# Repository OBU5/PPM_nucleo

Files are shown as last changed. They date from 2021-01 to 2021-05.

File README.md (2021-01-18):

# Proton precession magnetometer

Official repository for Proton precession magnetometer
In this repository are HW and SW files for the diploma thesis that is about designing, constrocting of proton precession magnetometer and analysis of its signal.
The aim is to construct PPM device that will be used for the earth’s magnetic field measurement

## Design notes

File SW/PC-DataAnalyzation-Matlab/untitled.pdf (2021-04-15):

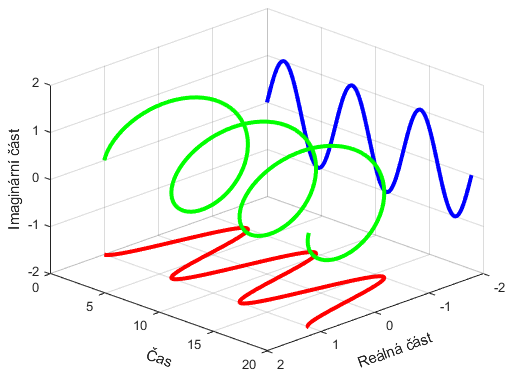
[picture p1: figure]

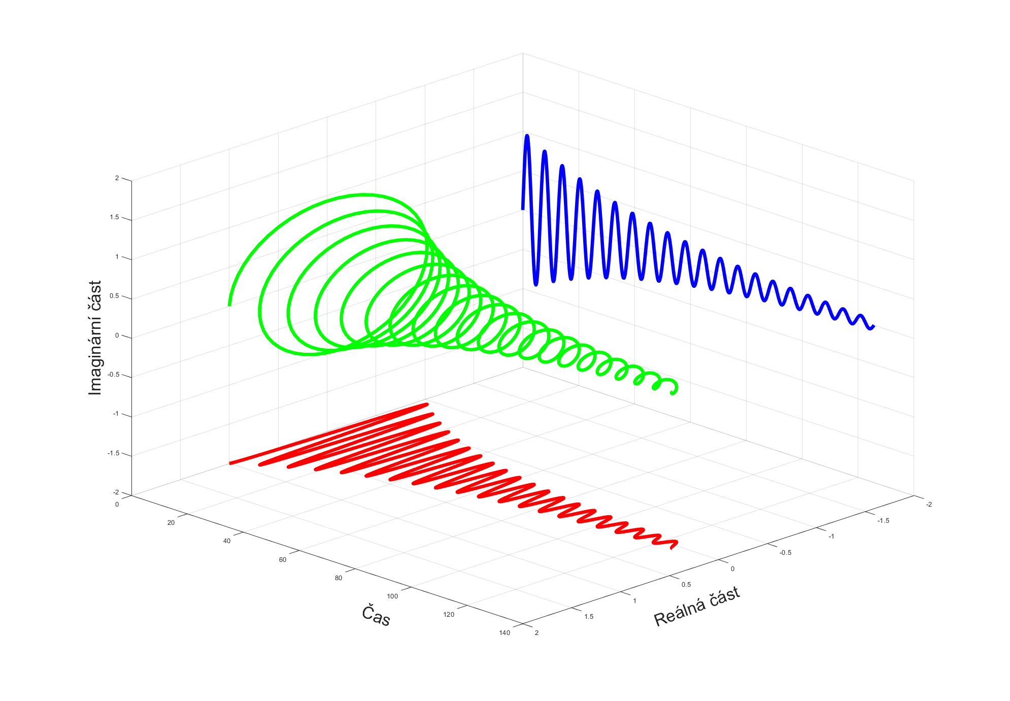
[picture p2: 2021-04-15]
SW/PC-DataAnalyzation-Matlab/complexGraph2.png

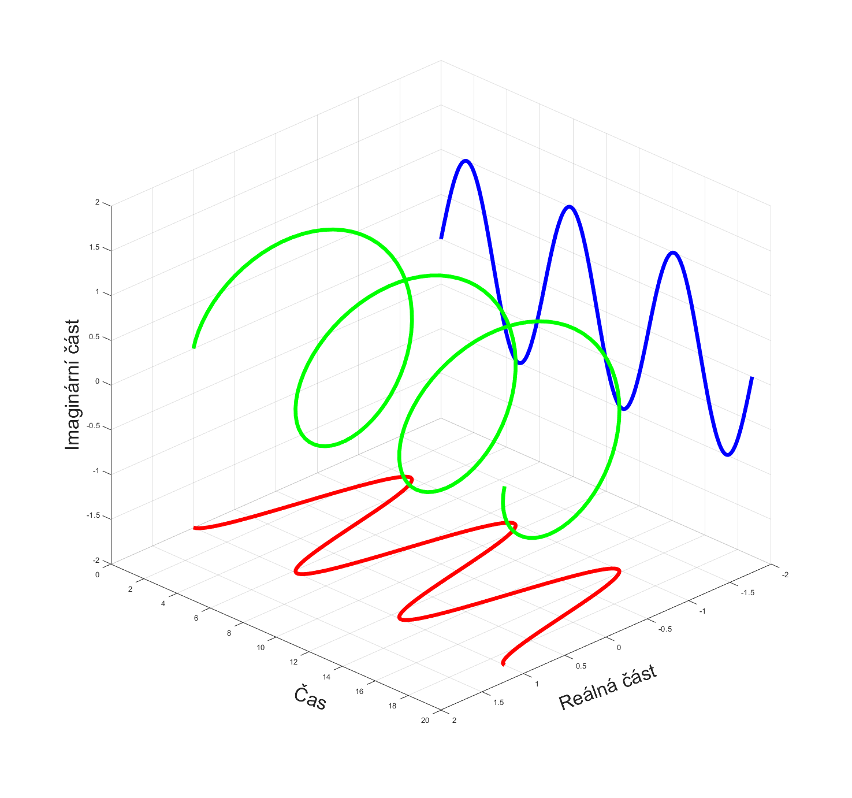
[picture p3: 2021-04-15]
SW/PC-DataAnalyzation-Matlab/complexGraph.png

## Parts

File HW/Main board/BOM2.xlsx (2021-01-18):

Ref | Value | Part | Footprint | Description | Code | count | which shopping cart | Column3 | Column6 | Column7 | Column8 | Column9 | Column10 | Column11 | Column12 | Column13 | Column14 | Column15 | Column16 | Column17 | Column18 | Column19 | Column20 | Column21 | Column22 | Column23 | Column24 | Column25 | Column26 | Column27 | Column28 | Column29 | Column30 | Column31 | Column32 | Column33 | Column34 | Column35 | Column36 | Column37 | Column38 | Column39 | Column40 | Column41 | Column42 | Column43 | Column44 | Column45 | Column46 | Column47 | Column48 | Column49 | Column50 | Column51 | Column52 | Column53 | Column54 | Column55 | Column56
Source: | C:\Users\obu\OneDrive\Documents\CVUT\ING\Diplomka\HW\Kicad\PPM\Ver. 1.6\PPM.sch
Date: | 11/26/2020 9:22:03 PM
Tool: | Eeschema (5.1.4)-1
Component Count: | 388
Ref | Value | Part | Footprint | Description | Vendor | kolik kusů | Jaký košík
BTN1 | User btn | Switch:SW_Push | Button_Switch_THT:SW_PUSH_6mm | Push button switch, generic, two pins | SKHHDTA010 | 3 | MOUSER
BTN2 | User btn | Switch:SW_Push | Button_Switch_THT:SW_PUSH_6mm | Push button switch, generic, two pins | SKHHDTA010 | 3 | MOUSER
BTN3 | RESET | Switch:SW_Push | Button_Switch_THT:SW_PUSH_6mm | Push button switch, generic, two pins | SKHHDTA010 | 3 | MOUSER
C1 | 100n | Device:C | Mylib_Footprints:C0805 | Unpolarized capacitor |  |  | Snad najdu ve škole
C2 | 10u | Device:C | Mylib_Footprints:C1206 | Unpolarized capacitor |  |  | Snad najdu ve škole
C3 | 100n | Device:C | Mylib_Footprints:C0805 | Unpolarized capacitor |  |  | Snad najdu ve škole
C4 | 10u | Device:C | Mylib_Footprints:C1206 | Unpolarized capacitor |  |  | Snad najdu ve škole
C5 | 100n | Device:C | Mylib_Footprints:C0805 | Unpolarized capacitor |  |  | Snad najdu ve škole
C6 | 10u | Device:C | Mylib_Footprints:C1206 | Unpolarized capacitor |  |  | Snad najdu ve škole
C7 | 100n | Device:C | Mylib_Footprints:C0805 | Unpolarized capacitor |  |  | Snad najdu ve škole
C8 | 10u | Device:C | Mylib_Footprints:C1206 | Unpolarized capacitor |  |  | Snad najdu ve škole
C9 | 100n | Device:C | Mylib_Footprints:C0805 | Unpolarized capacitor |  |  | Snad najdu ve škole
C10 | 10u | Device:C | Mylib_Footprints:C1206 | Unpolarized capacitor |  |  | Snad najdu ve škole
C11 | 10u | Device:C | Mylib_Footprints:C1206 | Unpolarized capacitor |  |  | Snad najdu ve škole
C12 | 10u | Device:C | Mylib_Footprints:C1206 | Unpolarized capacitor |  |  | Snad najdu ve škole
C13 | 100u tantal | Device:CP | Capacitor_Tantalum_SMD:CP_EIA-6032-28_Kemet-C | Polarized capacitor | T495C107K010ATE250 (https://cz.mouser.com/ProductDetail/KEMET/T495C107K010ATE250?qs=Dbnw6jgPYP7KOtkzNJv%252BLA%3D%3D) | 2 | MOUSER
C14 | 100u | Device:CP | Capacitor_THT:CP_Radial_D8.0mm_P3.50mm | Polarized capacitor | UPW1H101MPD | 2 | MOUSER
C15 | 1m | Device:CP | Capacitor_THT:CP_Radial_D12.5mm_P5.00mm | Polarized capacitor | EEU-FC1H102L | 1 | MOUSER
C16 | 100u | Device:CP | Capacitor_THT:CP_Radial_D8.0mm_P3.50mm | Polarized capacitor | UPW1H101MPD | 2 | MOUSER
C17 | 10u | Device:C | Mylib_Footprints:C1206 | Unpolarized capacitor |  |  | Snad najdu ve škole
C18 | 10n | Device:C | Mylib_Footprints:C0805 | Unpolarized capacitor |  |  | Snad najdu ve škole
C19 | 10u | Device:C | Mylib_Footprints:C1206 | Unpolarized capacitor |  |  | Snad najdu ve škole
C20 | 1u | Device:C | Mylib_Footprints:C0805 | Unpolarized capacitor |  |  | Snad najdu ve škole
C21 | 100n | Device:C | Capacitor_THT:C_Rect_L7.2mm_W2.5mm_P5.00mm_FKS2_FKP2_MKS2_MKP2 | Unpolarized capacitor | MMK5104J63J01L16.5TA18 | 8 | MOUSER
C22 | 100n | Device:C | Capacitor_THT:C_Rect_L7.2mm_W2.5mm_P5.00mm_FKS2_FKP2_MKS2_MKP2 | Unpolarized capacitor | MMK5104J63J01L16.5TA18 | 8 | MOUSER
C23 | 100n | Device:C | Capacitor_THT:C_Rect_L7.2mm_W2.5mm_P5.00mm_FKS2_FKP2_MKS2_MKP2 | Unpolarized capacitor | MMK5104J63J01L16.5TA18 | 8 | MOUSER
C24 | 100n | Device:C | Capacitor_THT:C_Rect_L7.2mm_W2.5mm_P5.00mm_FKS2_FKP2_MKS2_MKP2 | Unpolarized capacitor | MMK5104J63J01L16.5TA18 | 8 | MOUSER
C25 | 10u | Device:C | Mylib_Footprints:C1206 | Unpolarized capacitor |  |  | Snad najdu ve škole
C26 | 100n | Device:C | Mylib_Footprints:C0805 | Unpolarized capacitor |  |  | Snad najdu ve škole
C27 | 100n | Device:C | Capacitor_THT:C_Rect_L7.2mm_W2.5mm_P5.00mm_FKS2_FKP2_MKS2_MKP2 | Unpolarized capacitor | MMK5104J63J01L16.5TA18 | 8 | MOUSER
C28 | 100n | Device:C | Capacitor_THT:C_Rect_L7.2mm_W2.5mm_P5.00mm_FKS2_FKP2_MKS2_MKP2 | Unpolarized capacitor | MMK5104J63J01L16.5TA18 | 8 | MOUSER
C29 | 100n | Device:C | Capacitor_THT:C_Rect_L7.2mm_W2.5mm_P5.00mm_FKS2_FKP2_MKS2_MKP2 | Unpolarized capacitor | MMK5104J63J01L16.5TA18 | 8 | MOUSER
C30 | 100n | Device:C | Capacitor_THT:C_Rect_L7.2mm_W2.5mm_P5.00mm_FKS2_FKP2_MKS2_MKP2 | Unpolarized capacitor | MMK5104J63J01L16.5TA18 | 8 | MOUSER
C31 | 100n | Device:C | Mylib_Footprints:C0805 | Unpolarized capacitor |  |  | Snad najdu ve škole
C32 | 1u | Device:C | Mylib_Footprints:C0805 | Unpolarized capacitor |  |  | Snad najdu ve škole
C33 | 100n | Device:C | Mylib_Footprints:C0805 | Unpolarized capacitor |  |  | Snad najdu ve škole
C34 | 100n | Device:C | Mylib_Footprints:C0805 | Unpolarized capacitor |  |  | Snad najdu ve škole
C35 | 100n | Device:C | Mylib_Footprints:C0805 | Unpolarized capacitor |  |  | Snad najdu ve škole
C36 | 10u | Device:C | Mylib_Footprints:C1206 | Unpolarized capacitor |  |  | Snad najdu ve škole
C37 | 100u tantal | Device:CP | Capacitor_Tantalum_SMD:CP_EIA-7343-20_Kemet-V | Polarized capacitor | T495X107M025ATE150 | 1 | MOUSER
C38 | 100n | Device:C | Mylib_Footprints:C0805 | Unpolarized capacitor |  |  | Snad najdu ve škole
C39 | 10u | Device:C | Mylib_Footprints:C1206 | Unpolarized capacitor |  |  | Snad najdu ve škole
C40 | 100n | Device:C | Mylib_Footprints:C0805 | Unpolarized capacitor |  |  | Snad najdu ve škole
C41 | 100n | Device:C | Mylib_Footprints:C0805 | Unpolarized capacitor |  |  | Snad najdu ve škole
C42 | 10u | Device:C | Mylib_Footprints:C1206 | Unpolarized capacitor |  |  | Snad najdu ve škole
C43 | 100n | Device:C | Mylib_Footprints:C0805 | Unpolarized capacitor |  |  | Snad najdu ve škole
C44 | 4.3p | Device:C | Mylib_Footprints:C0805 | Unpolarized capacitor | 08055A4R3CAT2A | 2 | MOUSER
C45 | 100n | Device:C | Mylib_Footprints:C0805 | Unpolarized capacitor |  |  | Snad najdu ve škole
C46 | 100u tantal | Device:CP | Capacitor_Tantalum_SMD:CP_EIA-6032-28_Kemet-C | Polarized capacitor | T495C107K010ATE250 (https://cz.mouser.com/ProductDetail/KEMET/T495C107K010ATE250?qs=Dbnw6jgPYP7KOtkzNJv%252BLA%3D%3D) | 2 | MOUSER
C47 | 4.3p | Device:C | Mylib_Footprints:C0805 | Unpolarized capacitor | 08055A4R3CAT2A | 2 | MOUSER
C48 | 100p | Device:C | Mylib_Footprints:C0805 | Unpolarized capacitor | C0805C101G5HACTU | 2 | MOUSER
C49 | 100p | Device:C | Mylib_Footprints:C0805 | Unpolarized capacitor | C0805C101G5HACTU | 2 | MOUSER
C50 | 100n | Device:C | Mylib_Footprints:C0805 | Unpolarized capacitor |  |  | Snad najdu ve škole
C51 | 10u | Device:C | Mylib_Footprints:C1206 | Unpolarized capacitor |  |  | Snad najdu ve škole
C52 | 470u | Device:CP | Capacitor_THT:CP_Radial_D10.0mm_P5.00mm | Polarized capacitor | ESH477M050AH4AA | 1 | MOUSER
C53 | 2200p | Device:C | Mylib_Footprints:C0805 | Unpolarized capacitor | 08055C222M4T4A | 1 | MOUSER
C54 | 10u | Device:C | Mylib_Footprints:C1206 | Unpolarized capacitor |  |  | Snad najdu ve škole
C55 | 100n | Device:C | Mylib_Footprints:C0805 | Unpolarized capacitor |  |  | Snad najdu ve škole
C56 | 1u | Device:C | Mylib_Footprints:C0805 | Unpolarized capacitor |  |  | Snad najdu ve škole
C57 | 100n | Device:C | Mylib_Footprints:C0805 | Unpolarized capacitor |  |  | Snad najdu ve škole
C58 | 10u | Device:C | Mylib_Footprints:C1206 | Unpolarized capacitor |  |  | Snad najdu ve škole
C59 | 10u | Device:C | Mylib_Footprints:C1206 | Unpolarized capacitor |  |  | Snad najdu ve škole
C60 | 100n | Device:C | Mylib_Footprints:C0805 | Unpolarized capacitor |  |  | Snad najdu ve škole
C61 | 100n | Device:C | Mylib_Footprints:C0805 | Unpolarized capacitor |  |  | Snad najdu ve škole
C62 | 2.2u | Device:C | Mylib_Footprints:C1206 | Unpolarized capacitor | UMK212BB7225KG-T | 2 | MOUSER
C63 | 2.2u | Device:C | Mylib_Footprints:C1206 | Unpolarized capacitor | UMK212BB7225KG-T | 2 | MOUSER
C64 | 470n | Device:C | Mylib_Footprints:C0805 | Unpolarized capacitor | C0805C474M5REC7210 | 1 | MOUSER
C65 | 100n | Device:C | Mylib_Footprints:C0805 | Unpolarized capacitor |  |  | Snad najdu ve škole
C66 | 47u | Device:CP | Capacitor_Tantalum_SMD:CP_EIA-6032-28_Kemet-C | Polarized capacitor | T495C476K010ATE300 | 3 | MOUSER
C67 | 10u | Device:C | Mylib_Footprints:C1206 | Unpolarized capacitor |  |  | Snad najdu ve škole
C68 | 10p | Device:C | Mylib_Footprints:C0805 | Unpolarized capacitor | 08055C100KAT2A | 1 | MOUSER
C69 | 10u | Device:C | Mylib_Footprints:C1206 | Unpolarized capacitor |  |  | Snad najdu ve škole
C70 | 22u | Device:C | Mylib_Footprints:C1206 | Unpolarized capacitor |  | 1 | MOUSER
C71 | 1u | Device:C | Mylib_Footprints:C0805 | Unpolarized capacitor |  |  | Snad najdu ve škole
C72 | 100n | Device:C | Mylib_Footprints:C0805 | Unpolarized capacitor |  |  | Snad najdu ve škole
C73 | 100n | Device:C | Mylib_Footprints:C0805 | Unpolarized capacitor |  |  | Snad najdu ve škole
C74 | 100n | Device:C | Mylib_Footprints:C0805 | Unpolarized capacitor |  |  | Snad najdu ve škole
C75 | 10u | Device:C | Mylib_Footprints:C1206 | Unpolarized capacitor |  |  | Snad najdu ve škole
C76 | 1u | Device:C | Mylib_Footprints:C0805 | Unpolarized capacitor |  |  | Snad najdu ve škole
C77 | 100n | Device:C | Mylib_Footprints:C0805 | Unpolarized capacitor |  |  | Snad najdu ve škole
C78 | 10u | Device:C | Mylib_Footprints:C1206 | Unpolarized capacitor |  |  | Snad najdu ve škole
C79 | 100n | Device:C | Mylib_Footprints:C0805 | Unpolarized capacitor |  |  | Snad najdu ve škole
C80 | 10u | Device:C | Mylib_Footprints:C1206 | Unpolarized capacitor |  |  | Snad najdu ve škole
C81 | 1u | Device:C | Mylib_Footprints:C0805 | Unpolarized capacitor |  |  | Snad najdu ve škole
C82 | 100n | Device:C | Mylib_Footprints:C0805 | Unpolarized capacitor |  |  | Snad najdu ve škole
C83 | 100n | Device:C | Mylib_Footprints:C0805 | Unpolarized capacitor |  |  | Snad najdu ve škole
C84 | 10u | Device:C | Mylib_Footprints:C1206 | Unpolarized capacitor |  |  | Snad najdu ve škole
C85 | 100n | Device:C | Mylib_Footprints:C0805 | Unpolarized capacitor |  |  | Snad najdu ve škole
C86 | 100n | Device:C | Mylib_Footprints:C0805 | Unpolarized capacitor |  |  | Snad najdu ve škole
C87 | 100n | Device:C | Mylib_Footprints:C0805 | Unpolarized capacitor |  |  | Snad najdu ve škole
C88 | 100n | Device:C | Mylib_Footprints:C0805 | Unpolarized capacitor |  |  | Snad najdu ve škole
C89 | 100n | Device:C | Mylib_Footprints:C0805 | Unpolarized capacitor |  |  | Snad najdu ve škole
C90 | 1m | Device:CP | Capacitor_THT:CP_Radial_D10.0mm_P5.00mm | Polarized capacitor | EEU-FP1E102B | 1 | MOUSER
C91 | 10u | Device:C | Mylib_Footprints:C1206 | Unpolarized capacitor |  |  | Snad najdu ve škole
C92 | 10u | Device:C | Mylib_Footprints:C1206 | Unpolarized capacitor |  |  | Snad najdu ve škole
C93 | 100n | Device:C | Mylib_Footprints:C0805 | Unpolarized capacitor |  |  | Snad najdu ve škole
C94 | 1n | Device:C | Mylib_Footprints:C0805 | Unpolarized capacitor |  |  | Snad najdu ve škole
C95 | 100n | Device:C | Mylib_Footprints:C0805 | Unpolarized capacitor |  |  | Snad najdu ve škole
C96 | 100n | Device:C | Mylib_Footprints:C0805 | Unpolarized capacitor |  |  | Snad najdu ve škole
C97 | 47u | Device:CP | Capacitor_Tantalum_SMD:CP_EIA-6032-28_Kemet-C | Polarized capacitor | T495C476K010ATE300 | 3 | MOUSER
C98 | 47u | Device:CP | Capacitor_Tantalum_SMD:CP_EIA-6032-28_Kemet-C | Polarized capacitor | T495C476K010ATE300 | 3 | MOUSER
C99 | 10u | Device:C | Mylib_Footprints:C1206 | Unpolarized capacitor |  |  | Snad najdu ve škole
C100 | 100n | Device:C | Mylib_Footprints:C0805 | Unpolarized capacitor |  |  | Snad najdu ve škole
C101 | 10u | Device:C | Mylib_Footprints:C1206 | Unpolarized capacitor |  |  | Snad najdu ve škole
C102 | 100n | Device:C | Mylib_Footprints:C0805 | Unpolarized capacitor |  |  | Snad najdu ve škole
C103 | 10u | Device:C | Mylib_Footprints:C1206 | Unpolarized capacitor |  |  | Snad najdu ve škole
C104 | 100n | Device:C | Mylib_Footprints:C0805 | Unpolarized capacitor |  |  | Snad najdu ve škole
C105 | 100n | Device:C | Mylib_Footprints:C0805 | Unpolarized capacitor |  |  | Snad najdu ve škole
C106 | 100n | Device:C | Mylib_Footprints:C0805 | Unpolarized capacitor |  |  | Snad najdu ve škole
C107 | 10u | Device:C | Mylib_Footprints:C1206 | Unpolarized capacitor |  |  | Snad najdu ve škole
C108 | 10u | Device:C | Mylib_Footprints:C1206 | Unpolarized capacitor |  |  | Snad najdu ve škole
C109 | 10n | Device:C | Mylib_Footprints:C0805 | Unpolarized capacitor |  |  | Snad najdu ve škole
C110 | 470u | Device:CP | Capacitor_THT:CP_Radial_D8.0mm_P3.50mm | Polarized capacitor | EEU-FM1E471LJ | 1 | MOUSER
C111 | 10n | Device:C | Mylib_Footprints:C0805 | Unpolarized capacitor |  |  | Snad najdu ve škole
C112 | 100n | Device:C | Mylib_Footprints:C0805 | Unpolarized capacitor |  |  | Snad najdu ve škole
C113 | 100n | Device:C | Mylib_Footprints:C0805 | Unpolarized capacitor |  |  | Snad najdu ve škole
C114 | 100n | Device:C | Mylib_Footprints:C0805 | Unpolarized capacitor |  |  | Snad najdu ve škole
C115 | 100n | Device:C | Mylib_Footprints:C0805 | Unpolarized capacitor |  |  | Snad najdu ve škole
C116 | 100n | Device:C | Mylib_Footprints:C0805 | Unpolarized capacitor |  |  | Snad najdu ve škole
C117 | 100n | Device:C | Mylib_Footprints:C0805 | Unpolarized capacitor |  |  | Snad najdu ve škole
C118 | 1u | Device:C | Mylib_Footprints:C0805 | Unpolarized capacitor |  |  | Snad najdu ve škole
C119 | 1u | Device:C | Mylib_Footprints:C0805 | Unpolarized capacitor |  |  | Snad najdu ve škole
C120 | 100n | Device:C | Mylib_Footprints:C0805 | Unpolarized capacitor |  |  | Snad najdu ve škole
C121 | 10u | Device:C | Mylib_Footprints:C1206 | Unpolarized capacitor |  |  | Snad najdu ve škole
C122 | 100n | Device:C | Mylib_Footprints:C0805 | Unpolarized capacitor |  |  | Snad najdu ve škole
C123 | 10u | Device:C | Mylib_Footprints:C1206 | Unpolarized capacitor |  |  | Snad najdu ve škole
C124 | 10n | Device:C | Mylib_Footprints:C0805 | Unpolarized capacitor |  |  | Snad najdu ve škole
C125 | 100n | Device:C | Mylib_Footprints:C0805 | Unpolarized capacitor |  |  | Snad najdu ve škole
C126 | 100n | Device:C | Mylib_Footprints:C0805 | Unpolarized capacitor |  |  | Snad najdu ve škole
C127 | 100n | Device:C | Mylib_Footprints:C0805 | Unpolarized capacitor |  |  | Snad najdu ve škole
C128 | 100n | Device:C | Mylib_Footprints:C0805 | Unpolarized capacitor |  |  | Snad najdu ve škole
C129 | 100n | Device:C | Mylib_Footprints:C0805 | Unpolarized capacitor |  |  | Snad najdu ve škole
C130 | 100n | Device:C | Mylib_Footprints:C0805 | Unpolarized capacitor |  |  | Snad najdu ve škole
C131 | 100n | Device:C | Mylib_Footprints:C0805 | Unpolarized capacitor |  |  | Snad najdu ve škole
C132 | 47p | Device:C | Mylib_Footprints:C0805 | Unpolarized capacitor | C0805C470J5RACTU (https://cz.mouser.com/ProductDetail/KEMET/C0805C470J5RACTU/?qs=gt1LBUVyoHlbpLRjfP%252BJ1A%3D%3D) | 1 | MOUSER
C133 | 47p | Device:C | Mylib_Footprints:C0805 | Unpolarized capacitor | C0805C470J5RACTU (https://cz.mouser.com/ProductDetail/KEMET/C0805C470J5RACTU/?qs=gt1LBUVyoHlbpLRjfP%252BJ1A%3D%3D) | 1 | MOUSER
C134 | 4n7/2kV | Device:C | Mylib_Footprints:C1210 | Unpolarized capacitor | C1210C472KGRACTU (https://cz.mouser.com/ProductDetail/KEMET/C1210C472KGRACTU/?qs=7IaIRco65pl63KmzQFBq7Q%3D%3D) | 1 | MOUSER
C135 | 10n | Device:C | Mylib_Footprints:C0805 | Unpolarized capacitor |  |  | Snad najdu ve škole
C136 | 10u | Device:C | Mylib_Footprints:C1206 | Unpolarized capacitor |  |  | Snad najdu ve škole
C137 | 100n | Device:C | Mylib_Footprints:C0805 | Unpolarized capacitor |  |  | Snad najdu ve škole
C138 | 100n | Device:C | Mylib_Footprints:C0805 | Unpolarized capacitor |  |  | Snad najdu ve škole
C139 | 100n | Device:C | Mylib_Footprints:C0805 | Unpolarized capacitor |  |  | Snad najdu ve škole
C140 | 100n | Device:C | Mylib_Footprints:C0805 | Unpolarized capacitor |  |  | Snad najdu ve škole
C141 | 100n | Device:C | Mylib_Footprints:C0805 | Unpolarized capacitor |  |  | Snad najdu ve škole
C142 | 100n | Device:C | Mylib_Footprints:C0805 | Unpolarized capacitor |  |  | Snad najdu ve škole
C143 | 100n | Device:C | Mylib_Footprints:C0805 | Unpolarized capacitor |  |  | Snad najdu ve škole
D1 | 15V | Device:D_Zener | Mylib_Footprints:D_SOD-123 | Zener diode | BZT52C15-E3-18 | 2 | MOUSER
D2 | D_TVS | Device:D_TVS | Mylib_Footprints:D_SMC | Bidirectional transient-voltage-suppression diode | TPSMC20CA | 1 | MOUSER
D3 | MBRS1100 | Device:D_Schottky | Mylib_Footprints:D_SMB | Schottky diode | MBRS1100T3G | 1 | MOUSER
D4 | 3v3 | Device:D_Zener | Mylib_Footprints:D_SOD-123 | Zener diode | BZT52B3V3-TP | 2 | MOUSER
D5 | 3v3 | Device:D_Zener | Mylib_Footprints:D_SOD-123 | Zener diode | BZT52B3V3-TP | 2 | MOUSER
D6 | 15V | Device:D_Zener | Mylib_Footprints:D_SOD-123 | Zener diode | BZT52C15-E3-18 | 2 | MOUSER
D7 | zener/4v7 | Device:D_Zener | Mylib_Footprints:D_SOD-123 | Zener diode | BZT52C4V7-E3-08 | 1 | MOUSER
D8 | BAS86 | Device:D_Schottky | Mylib_Footprints:D_MiniMELF | Schottky diode | BAS86-M-18 | 2 | MOUSER
D9 | BAS86 | Device:D_Schottky | Mylib_Footprints:D_MiniMELF | Schottky diode | BAS86-M-18 | 2 | MOUSER
F1 | Fuse | Device:Fuse | Mylib_Footprints:Fuse_Holder-PTF15 | Fuse | 64600001003 | 1 | MOUSER
FB1 | Bead | Device:L_Core_Ferrite | Mylib_Footprints:R0805 | Inductor with ferrite core | MI0805J102R-10 | 25 | Snad najdu ve škole
FB2 | Bead | Device:L_Core_Ferrite | Mylib_Footprints:R0805 | Inductor with ferrite core | MI0805J102R-10 | 25 | Snad najdu ve škole
FB3 | Bead | Device:L_Core_Ferrite | Mylib_Footprints:R0805 | Inductor with ferrite core | MI0805J102R-10 | 25 | Snad najdu ve škole
FB4 | Bead | Device:L_Core_Ferrite | Mylib_Footprints:R0805 | Inductor with ferrite core | MI0805J102R-10 | 25 | Snad najdu ve škole
FB5 | Bead | Device:L_Core_Ferrite | Mylib_Footprints:R0805 | Inductor with ferrite core | MI0805J102R-10 | 25 | Snad najdu ve škole
FB6 | Bead | Device:L_Core_Ferrite | Mylib_Footprints:R0805 | Inductor with ferrite core | MI0805J102R-10 | 25 | Snad najdu ve škole
FB7 | Bead | Device:L_Core_Ferrite | Mylib_Footprints:R0805 | Inductor with ferrite core | MI0805J102R-10 | 25 | Snad najdu ve škole
FB8 | Bead | Device:L_Core_Ferrite | Mylib_Footprints:R0805 | Inductor with ferrite core | MI0805J102R-10 | 25 | Snad najdu ve škole
FB9 | Bead | Device:L_Core_Ferrite | Mylib_Footprints:R0805 | Inductor with ferrite core | MI0805J102R-10 | 25 | Snad najdu ve škole
FB10 | Bead | Device:L_Core_Ferrite | Mylib_Footprints:R0805 | Inductor with ferrite core | MI0805J102R-10 | 25 | Snad najdu ve škole
FB11 | Bead | Device:L_Core_Ferrite | Mylib_Footprints:R0805 | Inductor with ferrite core | MI0805J102R-10 | 25 | Snad najdu ve škole
FB12 | Bead | Device:L_Core_Ferrite | Mylib_Footprints:R0805 | Inductor with ferrite core | MI0805J102R-10 | 25 | Snad najdu ve škole
FB13 | Bead | Device:L_Core_Ferrite | Mylib_Footprints:R0805 | Inductor with ferrite core | MI0805J102R-10 | 25 | Snad najdu ve škole
FB14 | Bead | Device:L_Core_Ferrite | Mylib_Footprints:R0805 | Inductor with ferrite core | MI0805J102R-10 | 25 | Snad najdu ve škole
FB15 | Bead | Device:L_Core_Ferrite | Mylib_Footprints:R0805 | Inductor with ferrite core | MI0805J102R-10 | 25 | Snad najdu ve škole
FB16 | Bead | Device:L_Core_Ferrite | Mylib_Footprints:R0805 | Inductor with ferrite core | MI0805J102R-10 | 25 | Snad najdu ve škole
FB17 | Bead | Device:L_Core_Ferrite | Mylib_Footprints:R0805 | Inductor with ferrite core | MI0805J102R-10 | 25 | Snad najdu ve škole
FB18 | Bead | Device:L_Core_Ferrite | Mylib_Footprints:R0805 | Inductor with ferrite core | MI0805J102R-10 | 25 | Snad najdu ve škole
FB19 | bead | Device:R | Mylib_Footprints:R0805 | Resistor | MI0805J102R-10 | 25 | Snad najdu ve škole
FB20 | bead | Device:R | Mylib_Footprints:R0805 | Resistor | MI0805J102R-10 | 25 | Snad najdu ve škole
FB21 | bead | Device:R | Mylib_Footprints:R0805 | Resistor | MI0805J102R-10 | 25 | Snad najdu ve škole
FB22 | bead | Device:R | Mylib_Footprints:R0805 | Resistor | MI0805J102R-10 | 25 | Snad najdu ve škole
FB23 | bead | Device:R | Mylib_Footprints:R0805 | Resistor | MI0805J102R-10 | 25 | Snad najdu ve škole
FB24 | bead | Device:R | Mylib_Footprints:R0805 | Resistor | MI0805J102R-10 | 25 | Snad najdu ve škole
FB25 | Bead | Device:L_Core_Ferrite | Mylib_Footprints:R0805 | Inductor with ferrite core | MI0805J102R-10 | 25 | Snad najdu ve škole
J1 | 12V | Connector:Screw_Terminal_01x02 | Mylib_Footprints:TerminalBlock_2pin_Pitch5.08mm | Generic screw terminal, single row, 01x02, script generated (kicad-library-utils/schlib/autogen/connector/) |  |  | Snad najdu ve škole
J2 | PPM_sensor | MyLib-Modules:PPM_sensor | Mylib_Footprints:TerminalBlock_2pin_Pitch5.08mm | Generic screw terminal, single row, 01x02, script generated (kicad-library-utils/schlib/autogen/connector/) |  |  | Snad najdu ve škole
J3 | RS232 | Connector:Screw_Terminal_01x03 | Connector_PinHeader_2.54mm:PinHeader_1x03_P2.54mm_Vertical | Generic screw terminal, single row, 01x03, script generated (kicad-library-utils/schlib/autogen/connector/) |  |  | Snad najdu ve škole
J4 | USB_B | Connector:USB_A | Connector_USB:USB_B_OST_USB-B1HSxx_Horizontal | USB Type A connector | SS-52300-001 | 1 | Snad najdu ve škole
J5 | UART5 | Connector:Screw_Terminal_01x05 | Connector_PinHeader_2.54mm:PinHeader_1x05_P2.54mm_Vertical | Generic screw terminal, single row, 01x05, script generated (kicad-library-utils/schlib/autogen/connector/) |  |  | Snad najdu ve škole
J6 | SWD | Connector:Screw_Terminal_01x06 | Connector_PinHeader_2.54mm:PinHeader_1x06_P2.54mm_Vertical | Generic screw terminal, single row, 01x06, script generated (kicad-library-utils/schlib/autogen/connector/) |  |  | Snad najdu ve škole
J7 | External GPIOs | Connector:Screw_Terminal_01x13 | Connector_PinHeader_2.54mm:PinHeader_1x13_P2.54mm_Vertical | Generic screw terminal, single row, 01x13, script generated (kicad-library-utils/schlib/autogen/connector/) |  |  | Snad najdu ve škole
J8 | UART1 | Connector:Screw_Terminal_01x05 | Connector_PinHeader_2.54mm:PinHeader_1x05_P2.54mm_Vertical | Generic screw terminal, single row, 01x05, script generated (kicad-library-utils/schlib/autogen/connector/) |  |  | Snad najdu ve škole
J9 | Batt | Connector:Screw_Terminal_01x02 | Connector_PinHeader_2.54mm:PinHeader_1x02_P2.54mm_Vertical | Generic screw terminal, single row, 01x02, script generated (kicad-library-utils/schlib/autogen/connector/) |  |  | Snad najdu ve škole
JP8 | Ref select | Device:Jumper_NC_Dual | Mylib_Footprints:Jumper-3pin-P2.54+SMD | Dual jumper, normally closed |  |  | Snad najdu ve škole
JP9 | Ref select | Device:Jumper_NC_Dual | Mylib_Footprints:Jumper-3pin-P2.54+SMD | Dual jumper, normally closed |  |  | Snad najdu ve škole
JP10 | Ref select | Device:Jumper_NC_Dual | Mylib_Footprints:Jumper-3pin-P2.54+SMD | Dual jumper, normally closed |  |  | Snad najdu ve škole
JP11 | Ref select | Device:Jumper_NC_Dual | Mylib_Footprints:Jumper-3pin-P2.54+SMD | Dual jumper, normally closed |  |  | Snad najdu ve škole
JP1 | LDO-5V_supply | Device:Jumper_NC_Dual | Mylib_Footprints:Jumper-3pin-P2.54+SMD | Dual jumper, normally closed |  |  | Snad najdu ve škole
JP2 | no osc tune | Device:Jumper_NC_Small | Mylib_Footprints:Jumper-2pin-P2.54+SMD | Jumper, normally closed, small symbol |  |  | Snad najdu ve škole
JP3 | AMP1_OUT | Device:Jumper_NC_Small | Mylib_Footprints:Jumper-2pin-P2.54+SMD | Jumper, normally closed, small symbol |  |  | Snad najdu ve škole
JP4 | Reg_ON | Device:Jumper_NC_Small | Mylib_Footprints:Jumper-2pin-P2.54+SMD | Jumper, normally closed, small symbol |  |  | Snad najdu ve škole
JP5 | AMP1_IN | Device:Jumper_NC_Small | Mylib_Footprints:Jumper-2pin-P2.54+SMD | Jumper, normally closed, small symbol |  |  | Snad najdu ve škole
JP6 | no osc tune | Device:Jumper_NC_Small | Mylib_Footprints:Jumper-2pin-P2.54+SMD | Jumper, normally closed, small symbol |  |  | Snad najdu ve škole
JP7 | LDO-3V3_supply | Device:Jumper_NC_Dual | Mylib_Footprints:Jumper-3pin-P2.54+SMD | Dual jumper, normally closed |  |  | Snad najdu ve škole
JP8 | Ref select | Device:Jumper_NC_Dual | Mylib_Footprints:Jumper-3pin-P2.54+SMD | Dual jumper, normally closed |  |  | Snad najdu ve škole
JP9 | Ref select | Device:Jumper_NC_Dual | Mylib_Footprints:Jumper-3pin-P2.54+SMD | Dual jumper, normally closed |  |  | Snad najdu ve škole
JP10 | Ref select | Device:Jumper_NC_Dual | Mylib_Footprints:Jumper-3pin-P2.54+SMD | Dual jumper, normally closed |  |  | Snad najdu ve škole
JP11 | Ref select | Device:Jumper_NC_Dual | Mylib_Footprints:Jumper-3pin-P2.54+SMD | Dual jumper, normally closed |  |  | Snad najdu ve škole
JP12 | no osc tune | Device:Jumper_NC_Small | Mylib_Footprints:Jumper-2pin-P2.54+SMD | Jumper, normally closed, small symbol |  |  | Snad najdu ve škole
JP13 | SYNC | Device:Jumper_NC_Dual | Mylib_Footprints:Jumper-3pin-P2.54+SMD | Dual jumper, normally closed |  |  | Snad najdu ve škole
JP14 | AMP2_OUT | Device:Jumper_NC_Small | Mylib_Footprints:Jumper-2pin-P2.54+SMD | Jumper, normally closed, small symbol |  |  | Snad najdu ve škole
JP15 | Ref select | Device:Jumper_NC_Dual | Mylib_Footprints:Jumper-3pin-P2.54+SMD | Dual jumper, normally closed |  |  | Snad najdu ve škole
JP16 | AMP2_IN | Device:Jumper_NC_Small | Mylib_Footprints:Jumper-2pin-P2.54+SMD | Jumper, normally closed, small symbol |  |  | Snad najdu ve škole
JP17 | Ref select | Device:Jumper_NC_Dual | Mylib_Footprints:Jumper-3pin-P2.54+SMD | Dual jumper, normally closed |  |  | Snad najdu ve škole
JP18 | Ref select | Device:Jumper_NC_Dual | Mylib_Footprints:Jumper-3pin-P2.54+SMD | Dual jumper, normally closed |  |  | Snad najdu ve škole
JP19 | AMP3_IN | Device:Jumper_NC_Small | Mylib_Footprints:Jumper-2pin-P2.54+SMD | Jumper, normally closed, small symbol |  |  | Snad najdu ve škole
JP20 | AMP3_OUT | Device:Jumper_NC_Small | Mylib_Footprints:Jumper-2pin-P2.54+SMD | Jumper, normally closed, small symbol |  |  | Snad najdu ve škole
JP21 | Ref select | Device:Jumper_NC_Dual | Mylib_Footprints:Jumper-3pin-P2.54+SMD | Dual jumper, normally closed |  |  | Snad najdu ve škole
JP22 | Driver Enable | Device:Jumper_NC_Dual | Mylib_Footprints:Jumper-3pin-P2.54+SMD | Dual jumper, normally closed |  |  | Snad najdu ve škole
L1 | 10u | Device:L | Mylib_Footprints:Inductor_SRR1208 | Inductor | SRR1208-100ML | 1 | MOUSER
L2 | 2.2u | Device:L_Core_Ferrite | Mylib_Footprints:Inductor_SRR0604 | Inductor with ferrite core | SRR0604-2R2ML | 1 | MOUSER
L3 | 220uH | Device:L_Core_Ferrite | Mylib_Footprints:Inductor_12x12mm |  | 7447707221 | 1 | MOUSER
L4 | 20u | Device:L_Core_Ferrite | Mylib_Footprints:Inductor_SRR1208 | Inductor with ferrite core | SRR1208-220ML | 1 | MOUSER
LED1 | User LED | Device:LED_RGBA | Connector_PinHeader_2.54mm:PinHeader_1x04_P2.54mm_Vertical | Light emitting diode |  |  | Snad najdu ve škole
LED2 | User LED | Device:LED | Mylib_Footprints:LED-THT-3.0mm | RGB LED, red/green/blue/MOUSERde | WP154A4SEJ3VBDZGW/CA | 1 | MOUSER
LED3 | User LED | Device:LED | Mylib_Footprints:LED-THT-3.0mm | Light emitting diode |  |  | Snad najdu ve škole
LED4 | User LED | Device:LED | Mylib_Footprints:LED-THT-3.0mm | Light emitting diode |  |  | Snad najdu ve škole
LED5 | LED | Device:LED | Mylib_Footprints:LED-THT-3.0mm | Light emitting diode |  |  | Snad najdu ve škole
LED6 | RX | Device:LED | Mylib_Footprints:LED-THT-3.0mm | Light emitting diode |  |  | Snad najdu ve škole
LED7 | TX | Device:LED | Mylib_Footprints:LED-THT-3.0mm | Light emitting diode |  |  | Snad najdu ve škole
Q1 | DMPH4015SSSQ-13 | MyLib-Semiconductors:PMOS-Si4403DDY | Package_SO:SOIC-8_3.9x4.9mm_P1.27mm | P-MOSFET transistor, drain/gate/source | DMPH4015SSSQ-13 | 1 | MOUSER
Q2 | ZTX851 | Device:Q_NPN_EBC | Package_TO_SOT_THT:TO-92L_Inline | NPN transistor, emitter/base/collector | ZTX851 | 2 | MOUSER
Q3 | ZTX851 | Device:Q_NPN_EBC | Package_TO_SOT_THT:TO-92L_Inline | NPN transistor, emitter/base/collector | ZTX851 | 2 | MOUSER
Q4 | IRF9640 | Device:Q_PMOS_GDS | Package_TO_SOT_THT:TO-220-3_Vertical | P-MOSFET transistor, gate/drain/source | IRF9640PBF | 1 | MOUSER
Q5 | BC847 | Transistor_BJT:BC847 | Package_TO_SOT_SMD:SOT-23 | 0.1A Ic, 45V Vce, NPN Transistor, SOT-23 | BC847BLT1G | 9 | MOUSER
Q6 | IRF740 | Device:Q_NMOS_GDS | Package_TO_SOT_THT:TO-220-3_Vertical | N-MOSFET transistor, gate/drain/source | IRF740APBF | 4 | MOUSER
Q7 | IRF740 | Device:Q_NMOS_GDS | Package_TO_SOT_THT:TO-220-3_Vertical | N-MOSFET transistor, gate/drain/source | IRF740APBF | 4 | MOUSER
Q8 | IRF640 | Device:Q_NMOS_GDS | Package_TO_SOT_THT:TO-220-3_Vertical | N-MOSFET transistor, gate/drain/source | IRF640PBF | 1 | MOUSER
Q9 | IRF740 | Device:Q_NMOS_GDS | Package_TO_SOT_THT:TO-220-3_Vertical | N-MOSFET transistor, gate/drain/source | IRF740APBF | 4 | MOUSER
Q10 | IRF740 | Device:Q_NMOS_GDS | Package_TO_SOT_THT:TO-220-3_Vertical | N-MOSFET transistor, gate/drain/source | IRF740APBF | 4 | MOUSER
Q11 | BC847 | Transistor_BJT:BC847 | Package_TO_SOT_SMD:SOT-23 | 0.1A Ic, 45V Vce, NPN Transistor, SOT-23 | BC847BLT1G | 9 | MOUSER
Q12 | BC847 | Transistor_BJT:BC847 | Package_TO_SOT_SMD:SOT-23 | 0.1A Ic, 45V Vce, NPN Transistor, SOT-23 | BC847BLT1G | 9 | MOUSER
Q13 | BC847 | Transistor_BJT:BC847 | Package_TO_SOT_SMD:SOT-23 | 0.1A Ic, 45V Vce, NPN Transistor, SOT-23 | BC847BLT1G | 9 | MOUSER
Q14 | BC847 | Transistor_BJT:BC847 | Package_TO_SOT_SMD:SOT-23 | 0.1A Ic, 45V Vce, NPN Transistor, SOT-23 | BC847BLT1G | 9 | MOUSER
Q15 | BC847 | Transistor_BJT:BC847 | Package_TO_SOT_SMD:SOT-23 | 0.1A Ic, 45V Vce, NPN Transistor, SOT-23 | BC847BLT1G | 9 | MOUSER
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

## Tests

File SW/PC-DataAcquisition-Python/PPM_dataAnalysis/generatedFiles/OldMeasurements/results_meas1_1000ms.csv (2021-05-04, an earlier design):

time | hilbert transform | fft without zero padding | fft with zero padding (441000) | fft with zero padding (4410000) | comparator
0 | 49101.69729903833 | 49141.77993115235 | 49146.18662339063 | 49147.11168936412 | 49083.30755647067
8 | 49122.71036701152 | 49141.77993115235 | 49147.58199601451 | 49147.11168936412 | 49059.39355112096
16 | 49051.98172504753 | 49141.77993115235 | 49147.11687180656 | 49147.11168936412 | 49056.653941448676
24 | 48981.16668786069 | 49141.77993115235 | 49147.58199601451 | 49147.11168936412 | 49036.536131495064
32 | 48983.0383093827 | 49141.77993115235 | 49148.744806534414 | 49149.24879906057 | 48985.92349433245
40 | 49055.95030114873 | 49141.77993115235 | 49148.744806534414 | 49149.24879906057 | 49063.586591090854
48 | 49005.7471035668 | 49141.77993115235 | 49148.977368638385 | 49149.24879906057 | 49028.49435147816
56 | 48957.815392368255 | 49141.77993115235 | 49147.34943391054 | 49147.11168936412 | 49048.71311054642
64 | 49001.591992186695 | 49141.77993115235 | 49147.34943391054 | 49147.11168936412 | 49061.5766125794
72 | 48957.83788173205 | 49141.77993115235 | 49147.11687180656 | 49147.11168936412 | 49055.08670268836
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

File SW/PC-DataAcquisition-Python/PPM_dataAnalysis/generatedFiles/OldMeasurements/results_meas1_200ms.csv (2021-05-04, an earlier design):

time | hilbert transform | fft without zero padding | fft with zero padding (441000) | fft with zero padding (4410000) | comparator
0 | 49139.968161653946 | 49126.98149480398 | 49149.241224516605 | 49149.55954242922 | 49145.831630043824
8 | 49138.36418208907 | 49126.98149480398 | 49146.42819560037 | 49147.25464843455 | 49144.6369616814
16 | 49142.60015604502 | 49126.98149480398 | 49149.241224516605 | 49149.55954242922 | 49152.110186127524
24 | 49135.68251307219 | 49126.98149480398 | 49147.131452829424 | 49147.25464843455 | 49140.191426653604
32 | 49135.42802612591 | 49126.98149480398 | 49149.94448174567 | 49149.55954242922 | 49163.558761440356
40 | 49143.53023953903 | 49126.98149480398 | 49148.53796728755 | 49149.55954242922 | 49148.10686581635
48 | 49139.14486426754 | 49126.98149480398 | 49149.241224516605 | 49149.55954242922 | 49141.61182856221
56 | 49136.272291484456 | 49126.98149480398 | 49147.83471005849 | 49147.25464843455 | 49148.62661860904
64 | 49135.27936649996 | 49126.98149480398 | 49147.365871905786 | 49147.25464843455 | 49151.12592639579
72 | 49127.86829456382 | 49126.98149480398 | 49146.42819560037 | 49147.25464843455 | 49151.60108087259
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

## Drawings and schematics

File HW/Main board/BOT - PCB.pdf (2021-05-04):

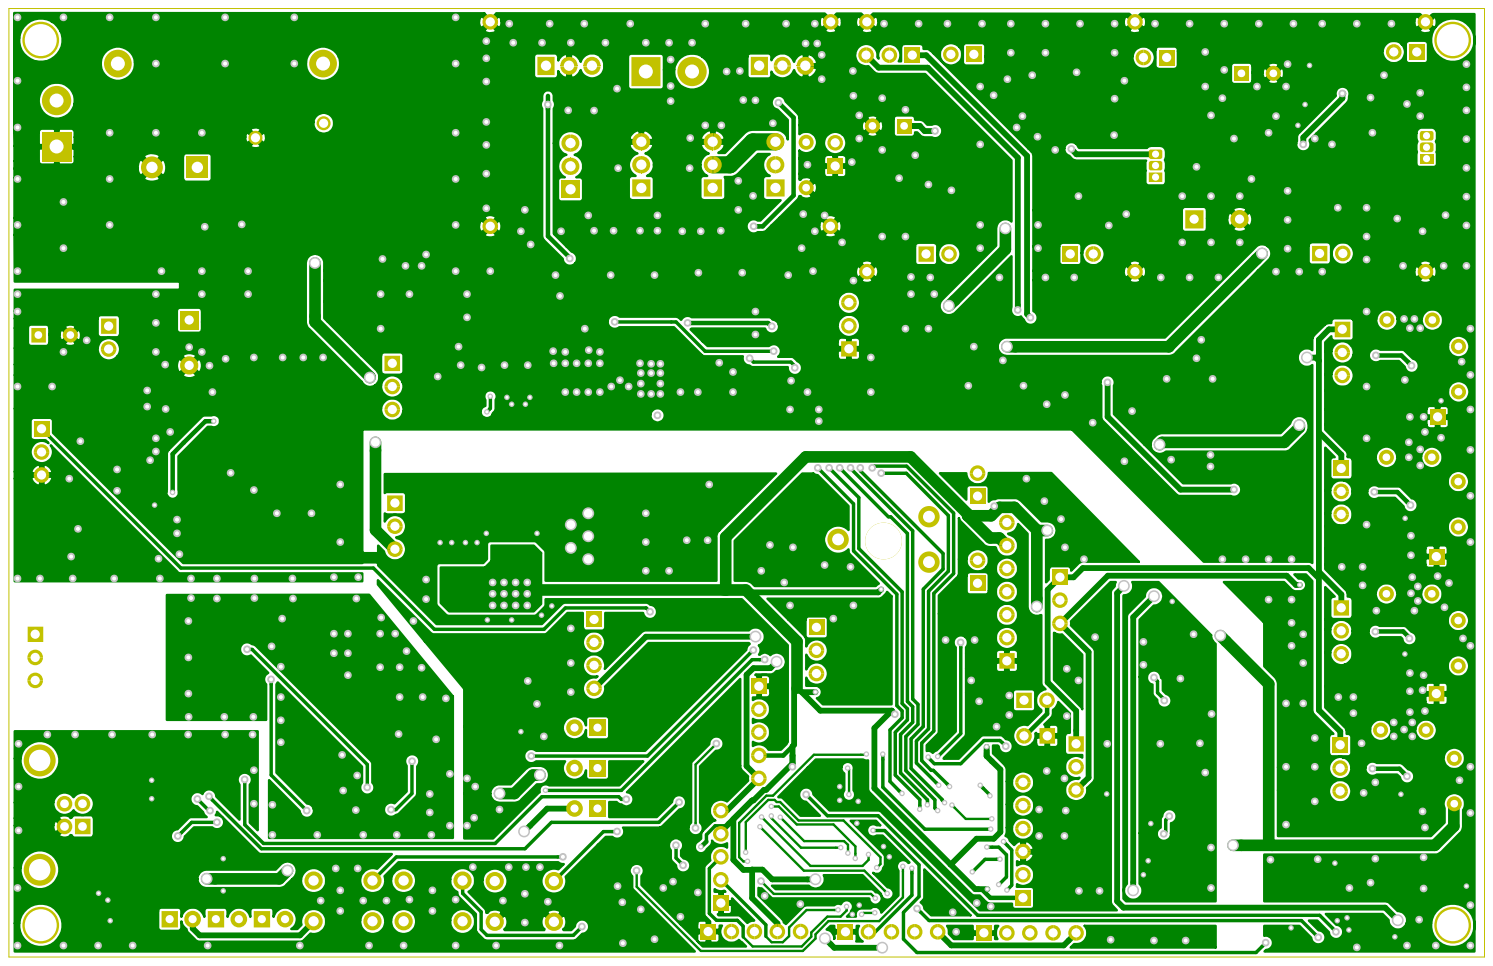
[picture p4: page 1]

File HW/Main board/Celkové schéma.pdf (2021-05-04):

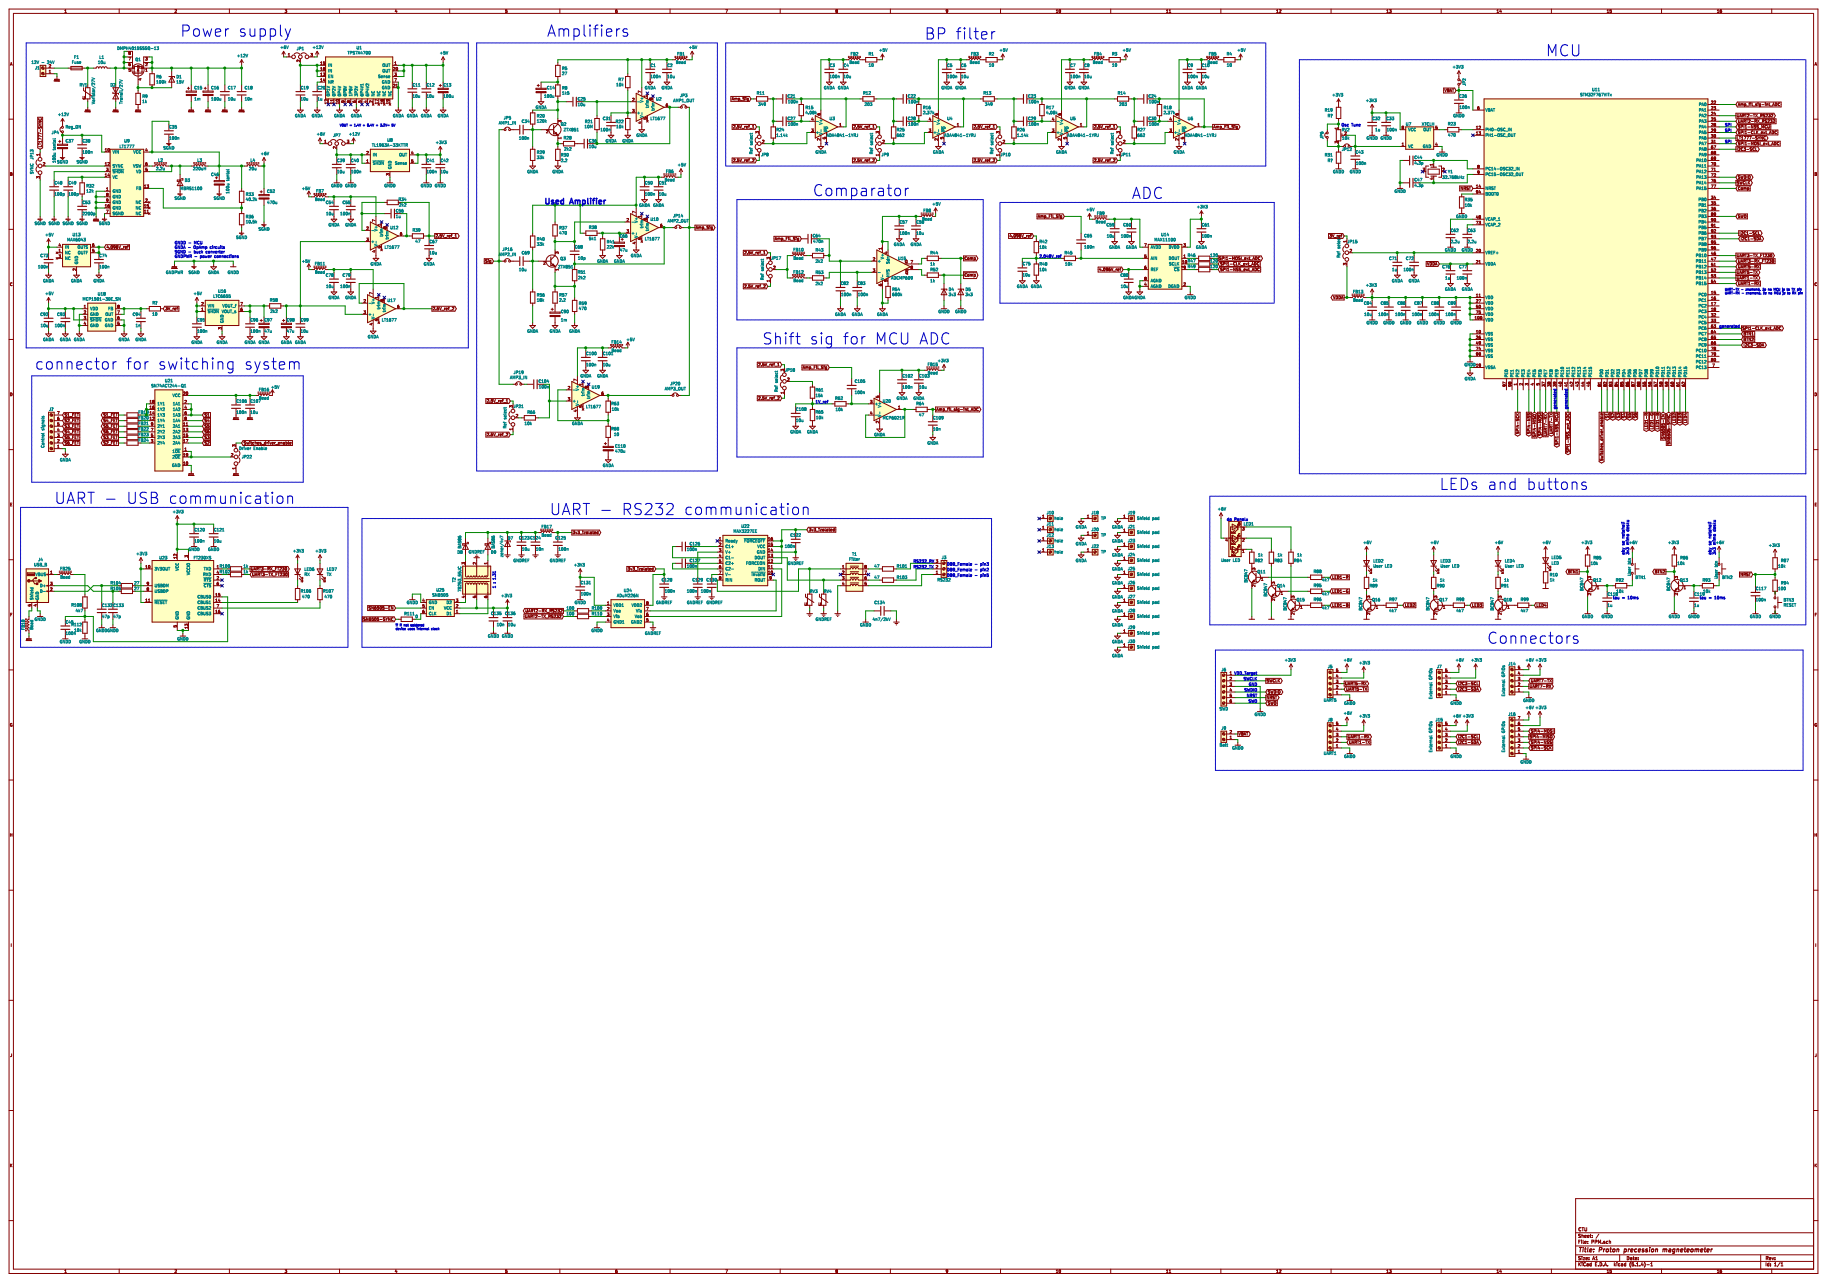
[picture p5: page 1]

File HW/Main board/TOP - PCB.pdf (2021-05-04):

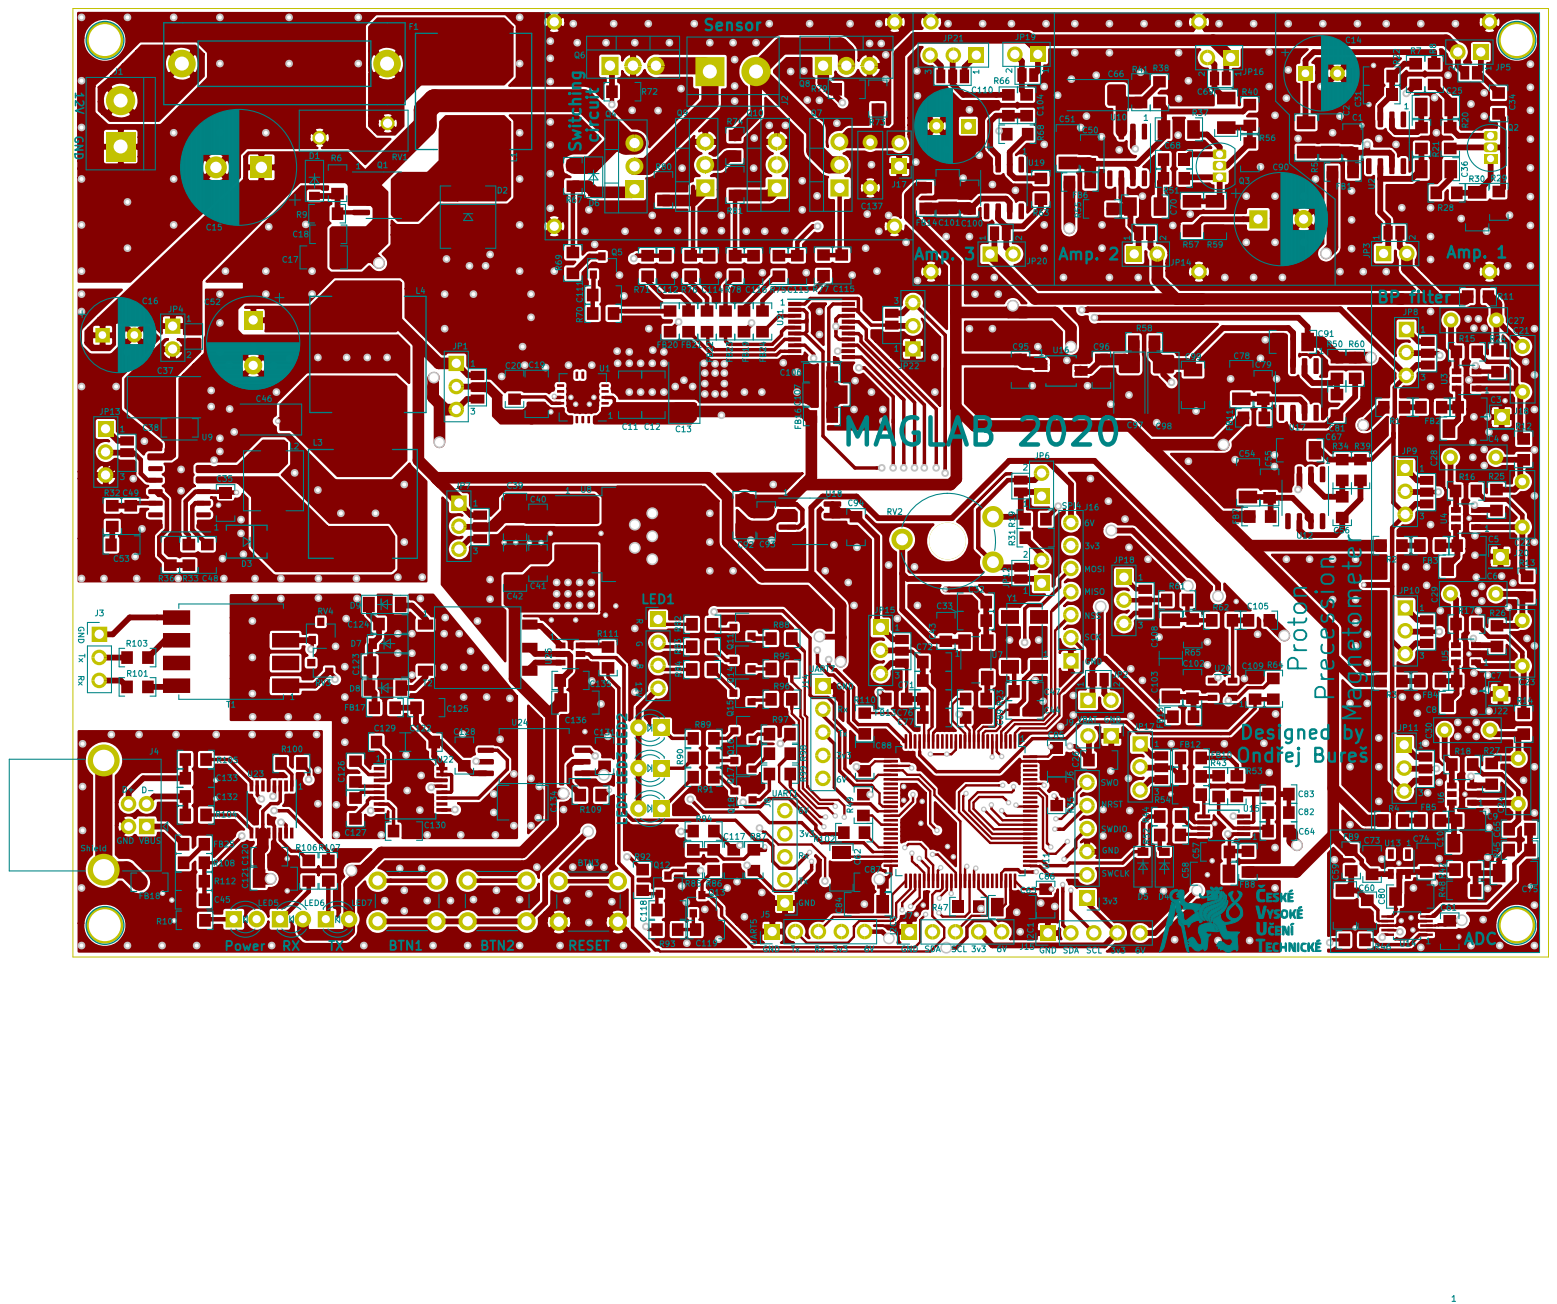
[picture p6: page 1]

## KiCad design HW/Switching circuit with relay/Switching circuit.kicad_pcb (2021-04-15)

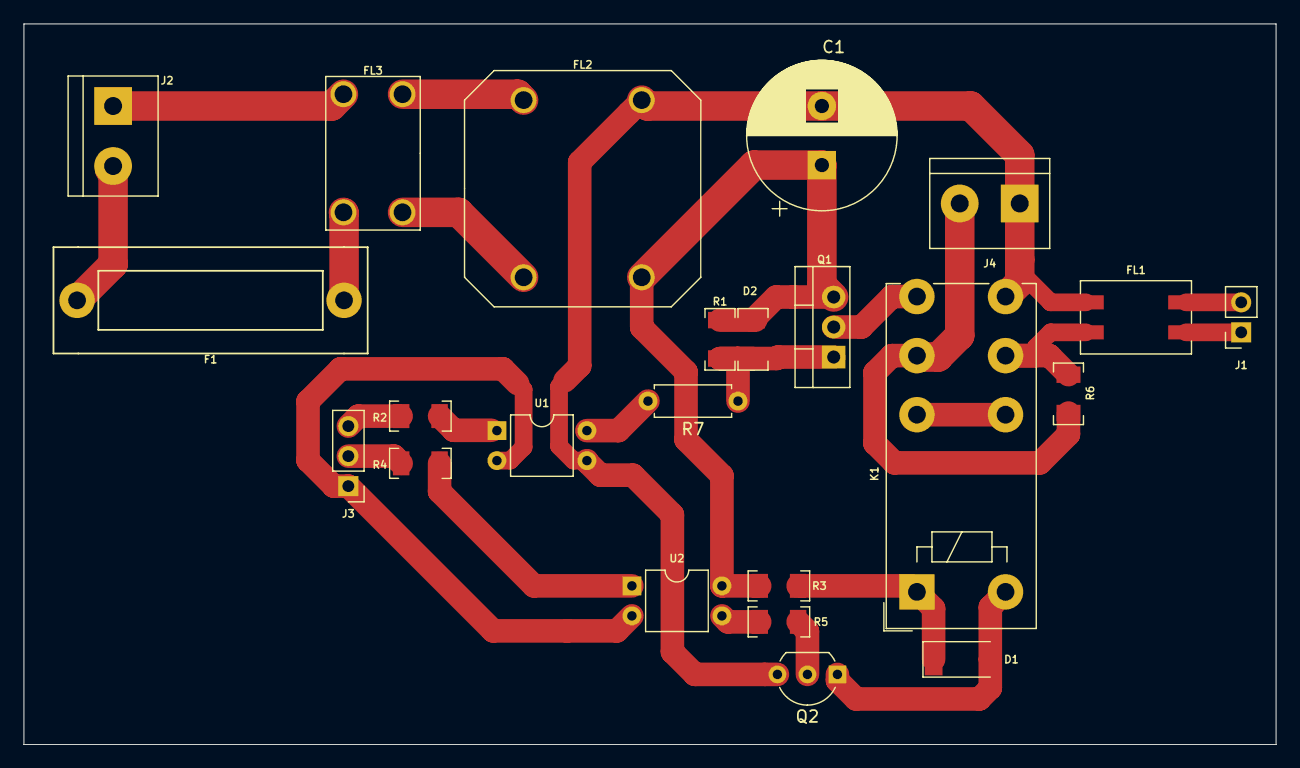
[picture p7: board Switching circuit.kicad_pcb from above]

Board: 2 copper layers, 106.0 x 61.0 mm, 23 parts (0 on the bottom side), 24 nets.

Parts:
C1: CP; CP_Radial_D12.5mm_P5.00mm
D1: D; D_MELF
D2: 15V; R1206
F1: Fuse; Fuse_Holder-PTF15
FL1: Filter; WE-SL2
FL2: Filter; Choke1
FL3: Filter; Choke2
J1: Signal; PinSocket_1x02_P2.54mm_Vertical
J2: Power; TerminalBlock_2pin_Pitch5.08mm
J3: MCU; PinHeader_1x03_P2.54mm_Vertical
J4: PPM_sensor; TerminalBlock_2pin_Pitch5.08mm
K1: FINDER-41.52; Relay_DPDT_Finder_40.52
Q1: IRF9640; TO-220-3_Vertical
Q2: BC547; TO-92_Inline_Wide
R1: 2k2; R1206
R2, R4: 470; R1206
R3: 0; R1206
R5: 4k7; R1206
R6: 10k; R1206
R7: 1k; R_Axial_DIN0207_L6.3mm_D2.5mm_P7.62mm_Horizontal
U1, U2: LTV-817; DIP-4_W7.62mm

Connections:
+12V: C1.1, D2.1, FL2.3, Q1.3, R1.1, R3.1, U2.4
FET: J3.3, R2.2
GNDA: C1.2, FL1.1, FL2.4, J4.1, K1.24, Q2.3, U1.3
GNDD: J3.1, U1.2, U2.2
unnamed: D1.1, K1.A1, R3.2
unnamed: D1.2, K1.A2, Q2.1
unnamed: D2.2, Q1.1, R1.2, R7.1
unnamed: F1.1, FL3.2
unnamed: F1.2, J2.2
unnamed: FL1.3, J1.1
unnamed: FL1.4, J1.2
unnamed: FL2.1, FL3.4
unnamed: FL2.2, FL3.3
unnamed: FL3.1, J2.1
unnamed: J4.2, K1.11, R6.2
unnamed: K1.12, K1.22
unnamed: K1.14, Q1.2
unnamed: Q2.2, R5.2
unnamed: R2.1, U1.1
unnamed: R4.1, U2.1
unnamed: R5.1, U2.3
unnamed: R7.2, U1.4
Relay: J3.2, R4.2
Sig_out: FL1.2, K1.21, R6.1

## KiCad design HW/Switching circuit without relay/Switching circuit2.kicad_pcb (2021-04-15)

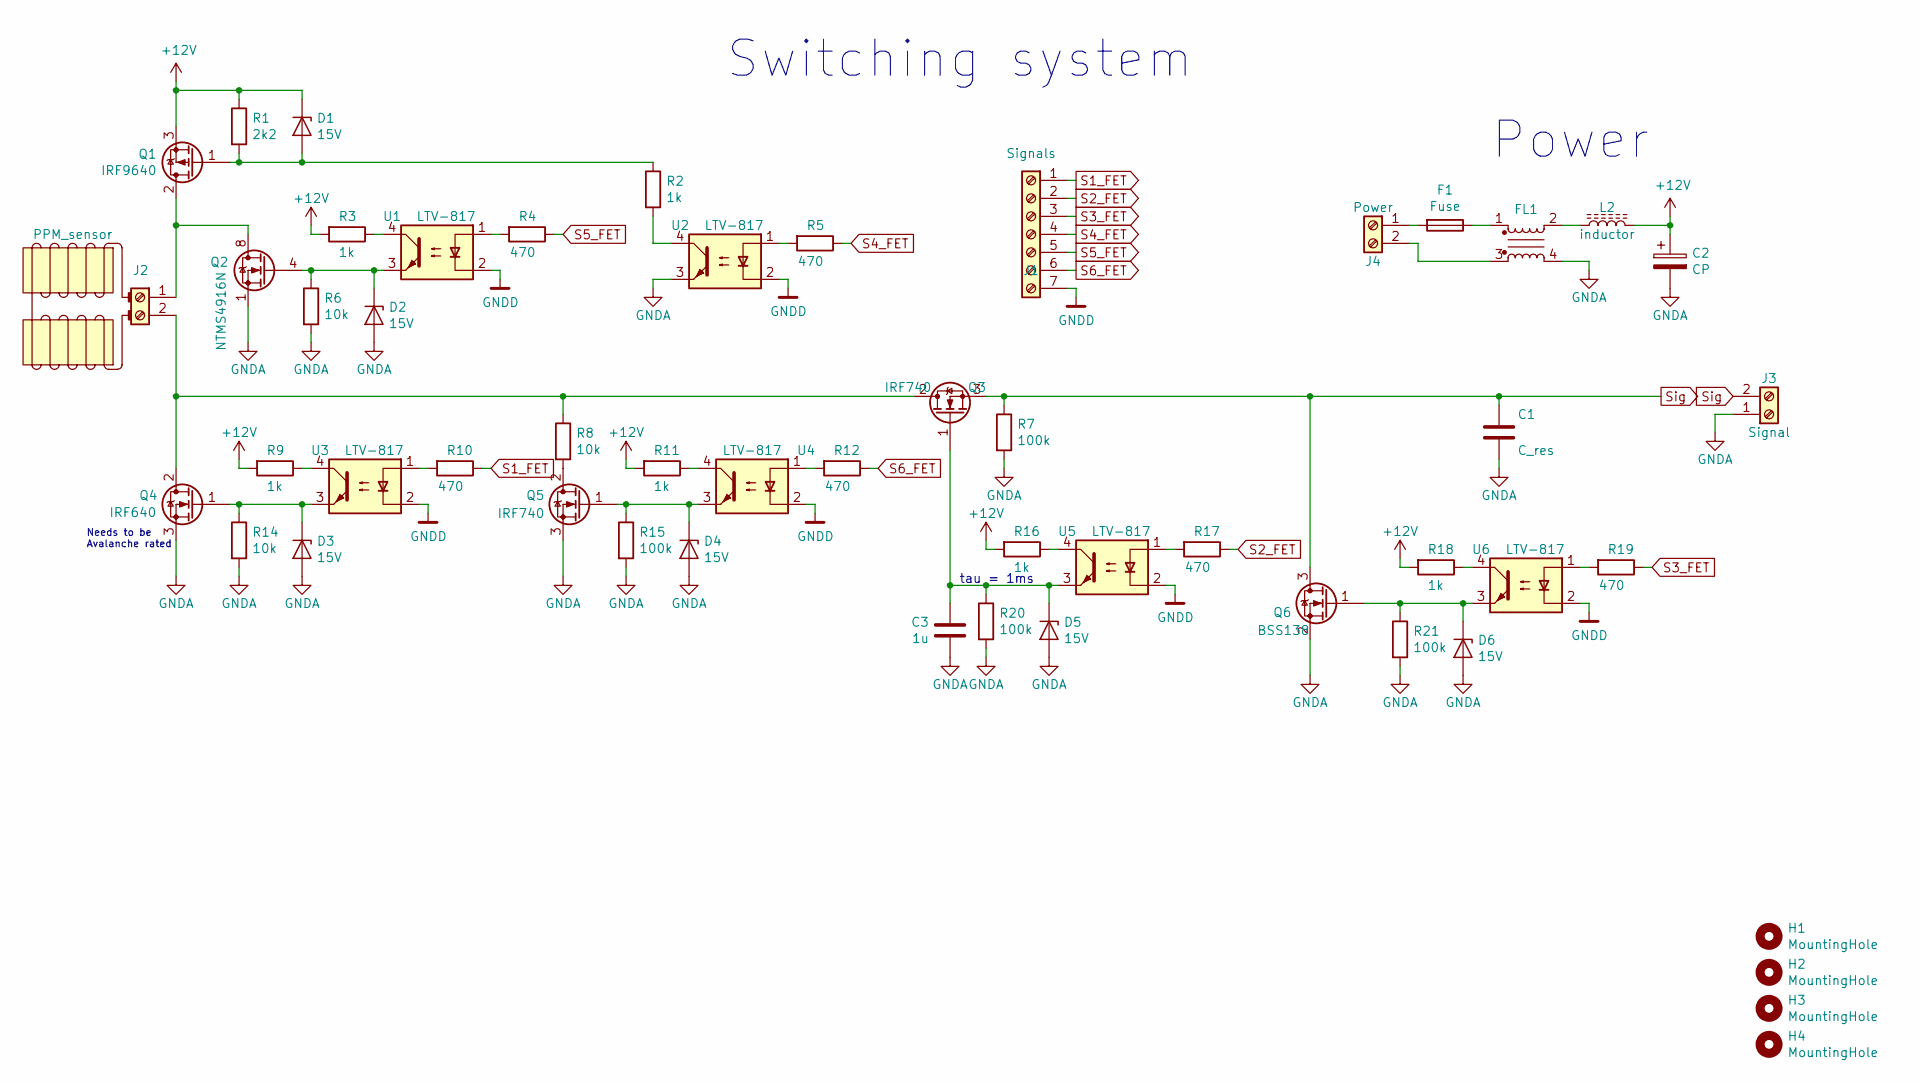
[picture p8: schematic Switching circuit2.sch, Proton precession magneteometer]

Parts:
C1: C_res; PinHeader_1x02_P2.54mm_Vertical
C2: CP; CP_Radial_D12.5mm_P5.00mm
C3: 1u
D1, D2, D3, D4, D5, D6: 15V; D_SOD-123
F1: Fuse; Fuse_Holder-PTF15
FL1: EMI_Filter_CommonMode; Choke1
H1, H2, H3, H4: MountingHole; Screwh_hole-3.5mm
J1: Signals; PinHeader_1x07_P2.54mm_Vertical
J2: PPM_sensor; TerminalBlock_2pin_Pitch5.08mm
J3: Signal; PinHeader_1x02_P2.54mm_Vertical
J4: Power; TerminalBlock_2pin_Pitch5.08mm
L2: inductor; Inductor_SRR1208
Q1: IRF9640; TO-220-3_Vertical
Q2: NTMS4916N; SOIC-8_3.9x4.9mm_P1.27mm
Q3, Q5: IRF740; TO-220-3_Vertical
Q4: IRF640; TO-220-3_Vertical
Q6: BSS138; SOT-23
R1: 2k2; R1206
R2, R3, R9, R11, R16, R18: 1k; R1206
R4, R5, R10, R12, R17, R19: 470; R1206
R6, R8, R14: 10k; R1206
R7, R15, R20, R21: 100k; R1206
U1, U2, U3, U4, U5, U6: LTV-817; DIP-4_W8.89mm_SMDSocket_LongPads

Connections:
+12V: C2.1, D1.1 (K), L2.2, Q1.3 (S), R1.1, R3.2, R9.2, R11.2, R16.2, R18.2
GNDA: C1.2, C2.2, C3.1, D2.2 (A), D3.2 (A), D4.2 (A), D5.2 (A), D6.2 (A), FL1.4, J3.1, Q2.1 (S), Q2.2 (S), Q2.3 (S), Q4.3 (S), Q5.3 (S), Q6.2 (S), R6.2, R7.2, R14.2, R15.2, R20.2, R21.2, U2.3
GNDD: J1.7, U1.2, U2.2, U3.2, U4.2, U5.2, U6.2
unnamed: C1.1, J3.2, Q3.3 (S), Q6.3 (D), R7.1
unnamed: D1.2 (A), Q1.1 (G), R1.2, R2.1
unnamed: D2.1 (K), Q2.4 (G), R6.1, U1.3
unnamed: D3.1 (K), Q4.1 (G), R14.1, U3.3
unnamed: D4.1 (K), Q5.1 (G), R15.1, U4.3
unnamed: C3.2, D5.1 (K), Q3.1 (G), R20.1, U5.3
unnamed: D6.1 (K), Q6.1 (G), R21.1, U6.3
unnamed: F1.1, FL1.1
unnamed: F1.2, J4.1
unnamed: FL1.2, L2.1
unnamed: FL1.3, J4.2
unnamed: J2.1, Q1.2 (D), Q2.5 (D), Q2.6 (D), Q2.7 (D), Q2.8 (D)
unnamed: J2.2, Q3.2 (D), Q4.2 (D), R8.1
unnamed: Q5.2 (D), R8.2
unnamed: R2.2, U2.4
unnamed: R3.1, U1.4
unnamed: R4.2, U1.1
unnamed: R5.2, U2.1
unnamed: R9.1, U3.4
unnamed: R10.2, U3.1
unnamed: R11.1, U4.4
unnamed: R12.2, U4.1
unnamed: R16.1, U5.4
unnamed: R17.2, U5.1
unnamed: R18.1, U6.4
unnamed: R19.2, U6.1
S1_FET: J1.1, R10.1
S2_FET: J1.2, R17.1
S3_FET: J1.3, R19.1
S4_FET: J1.4, R5.1
S5_FET: J1.5, R4.1
S6_FET: J1.6, R12.1

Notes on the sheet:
Needs to be Avalanche rated
Switching system
Power
tau = 1ms

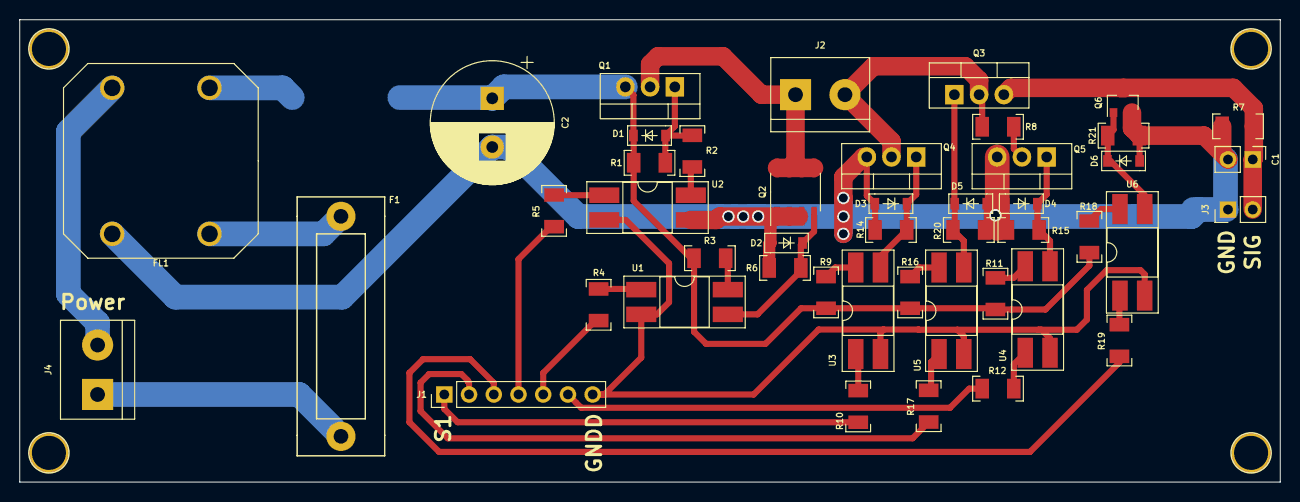
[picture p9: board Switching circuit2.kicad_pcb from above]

Board: 2 copper layers, 129.5 x 47.5 mm, 51 parts (1 on the bottom side), 35 nets.

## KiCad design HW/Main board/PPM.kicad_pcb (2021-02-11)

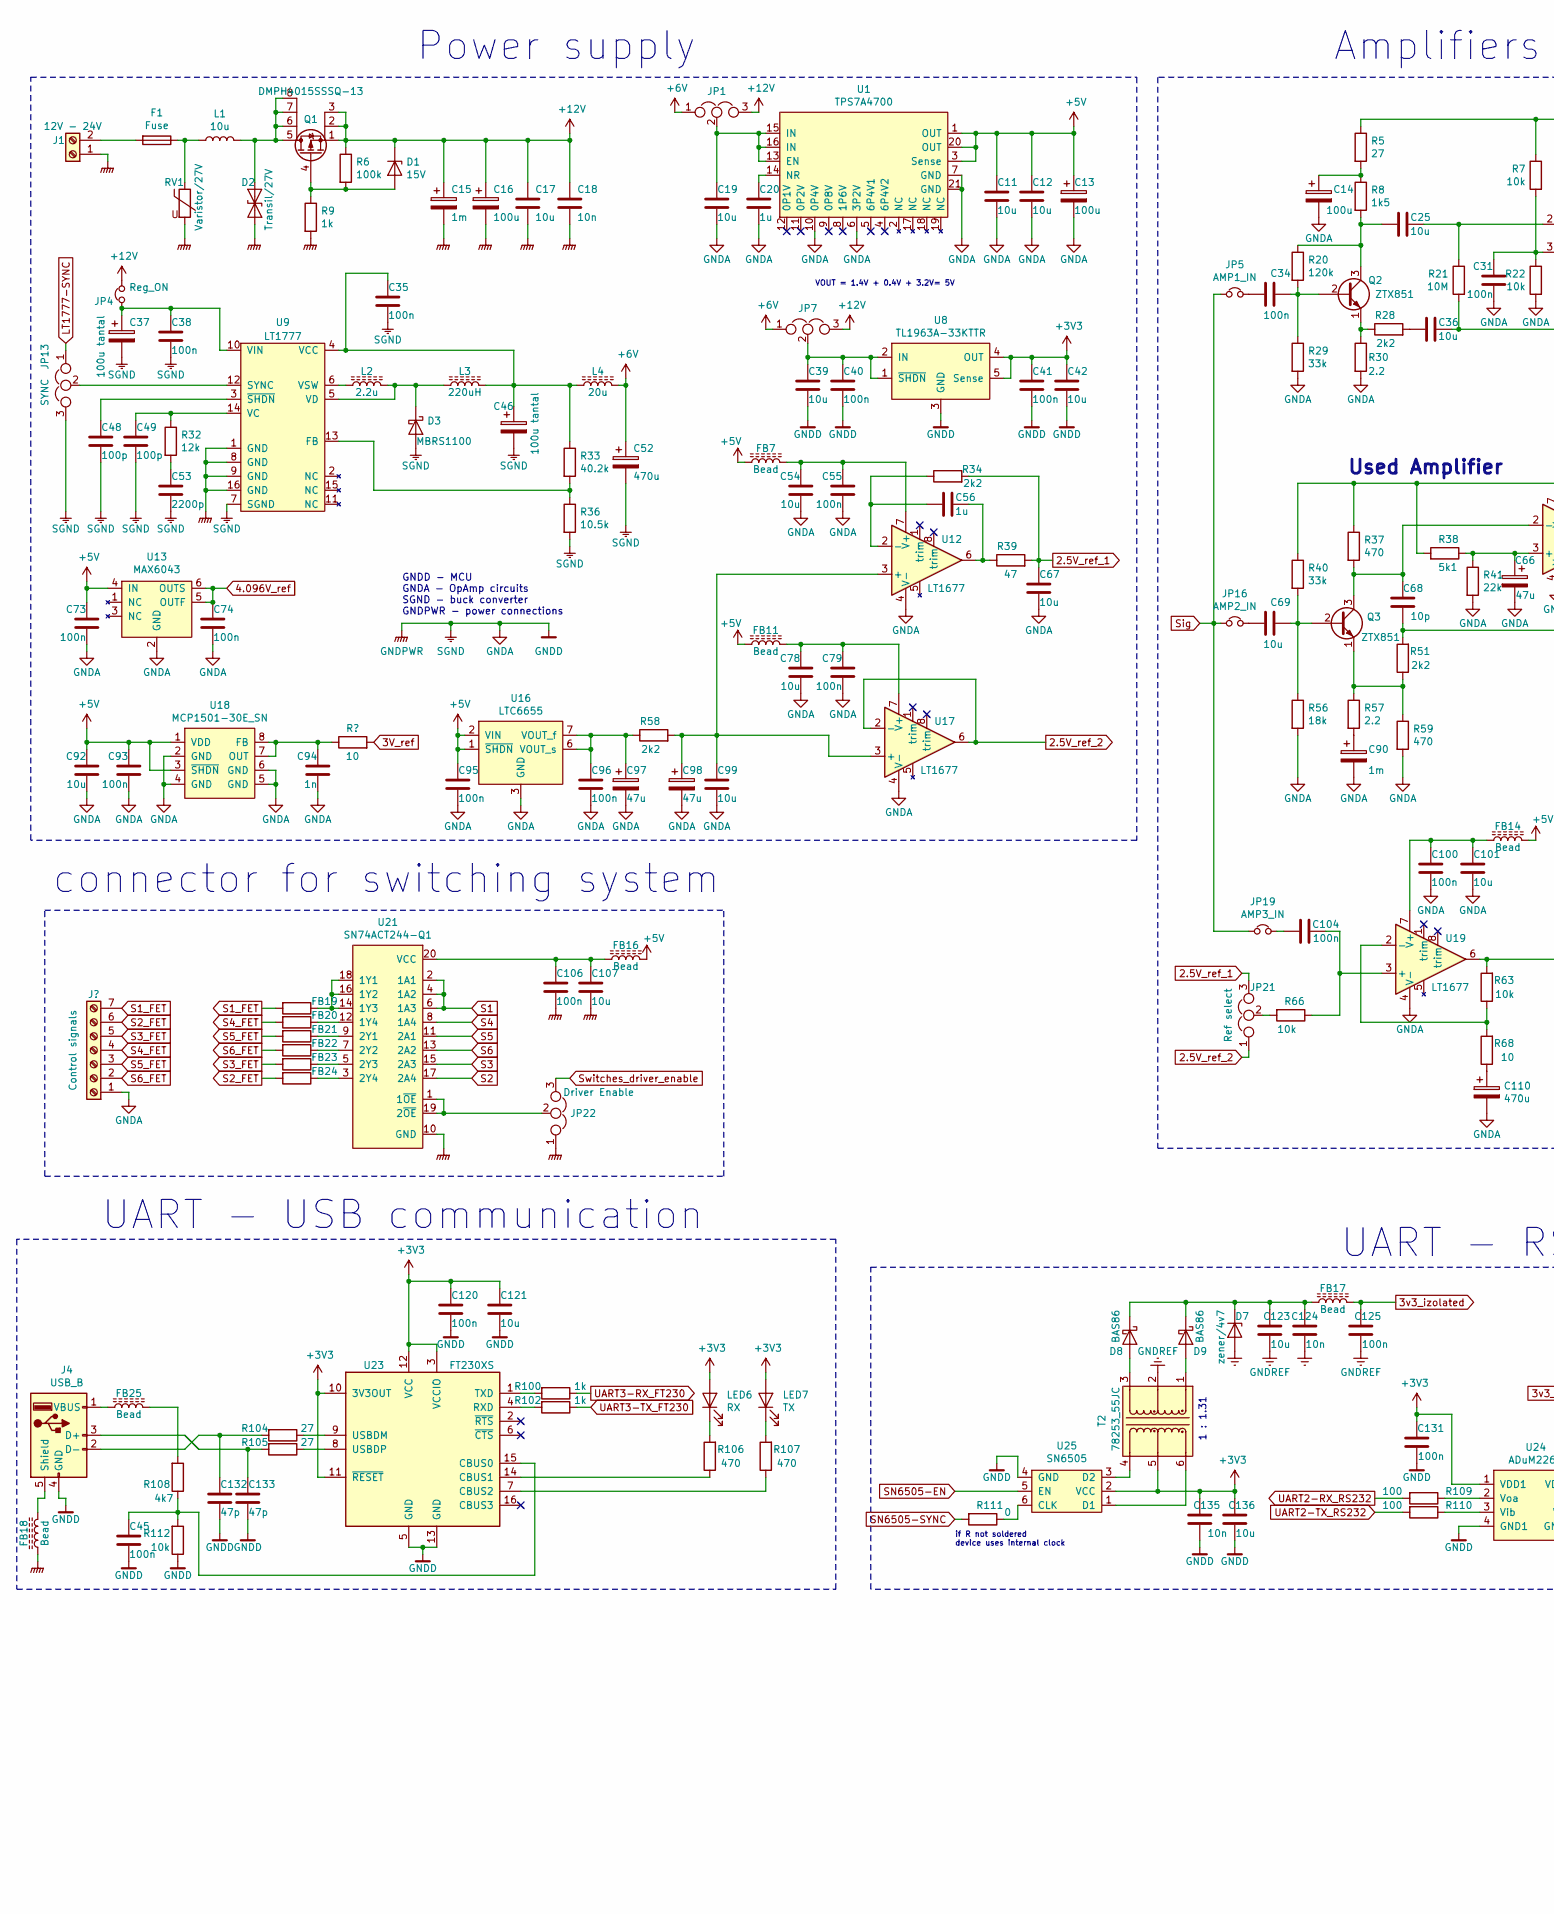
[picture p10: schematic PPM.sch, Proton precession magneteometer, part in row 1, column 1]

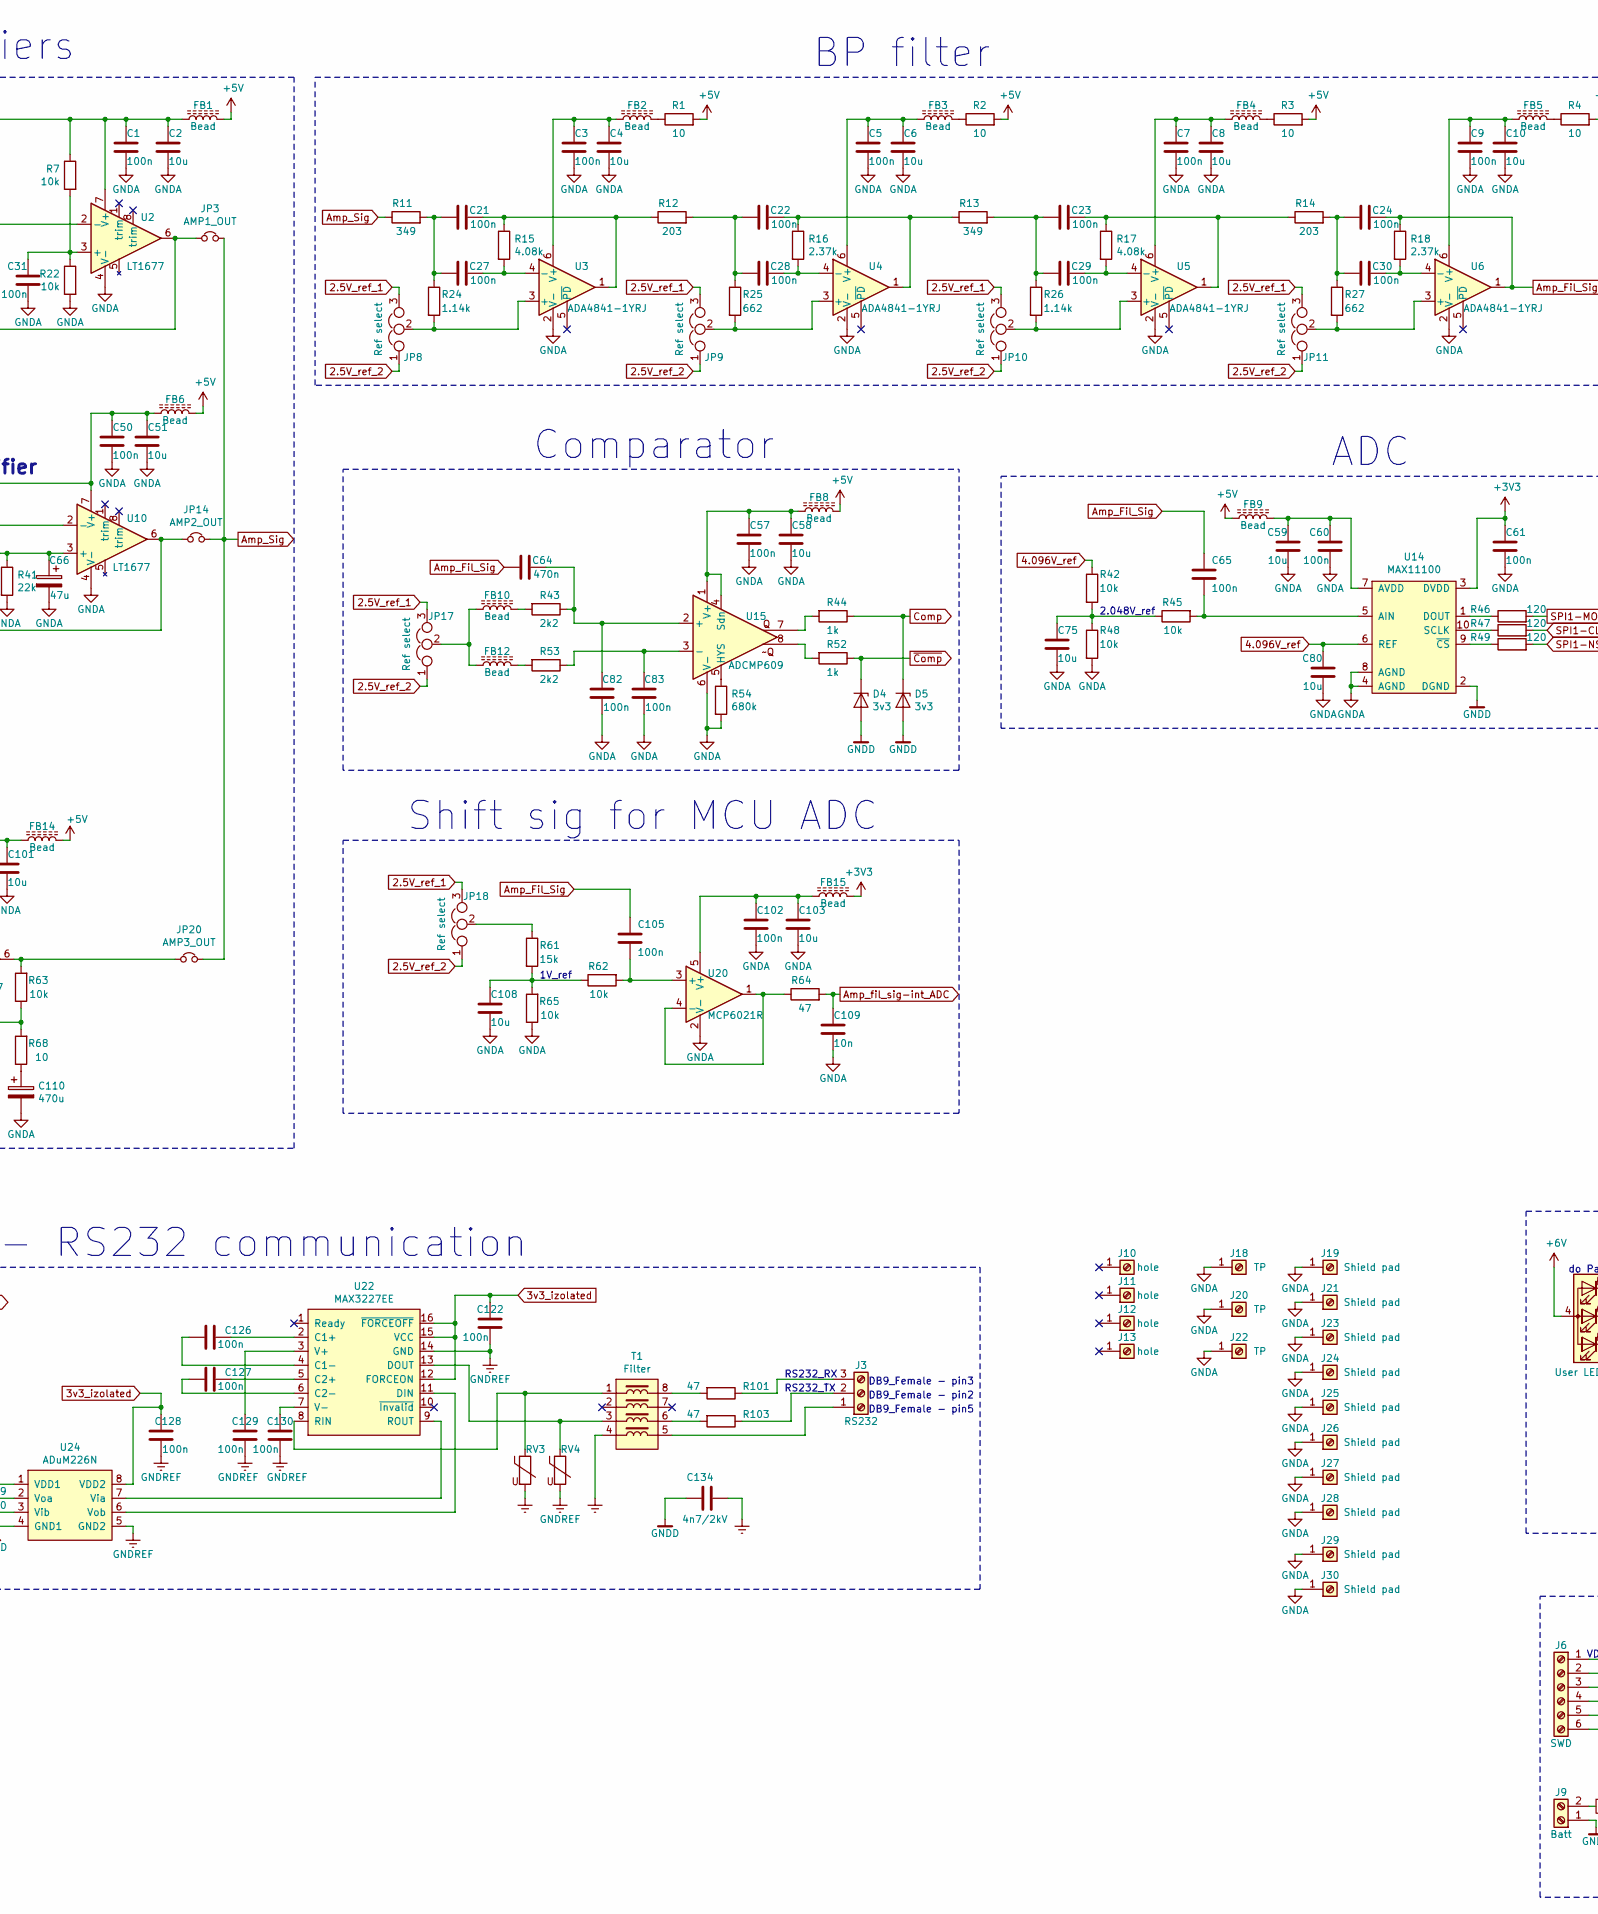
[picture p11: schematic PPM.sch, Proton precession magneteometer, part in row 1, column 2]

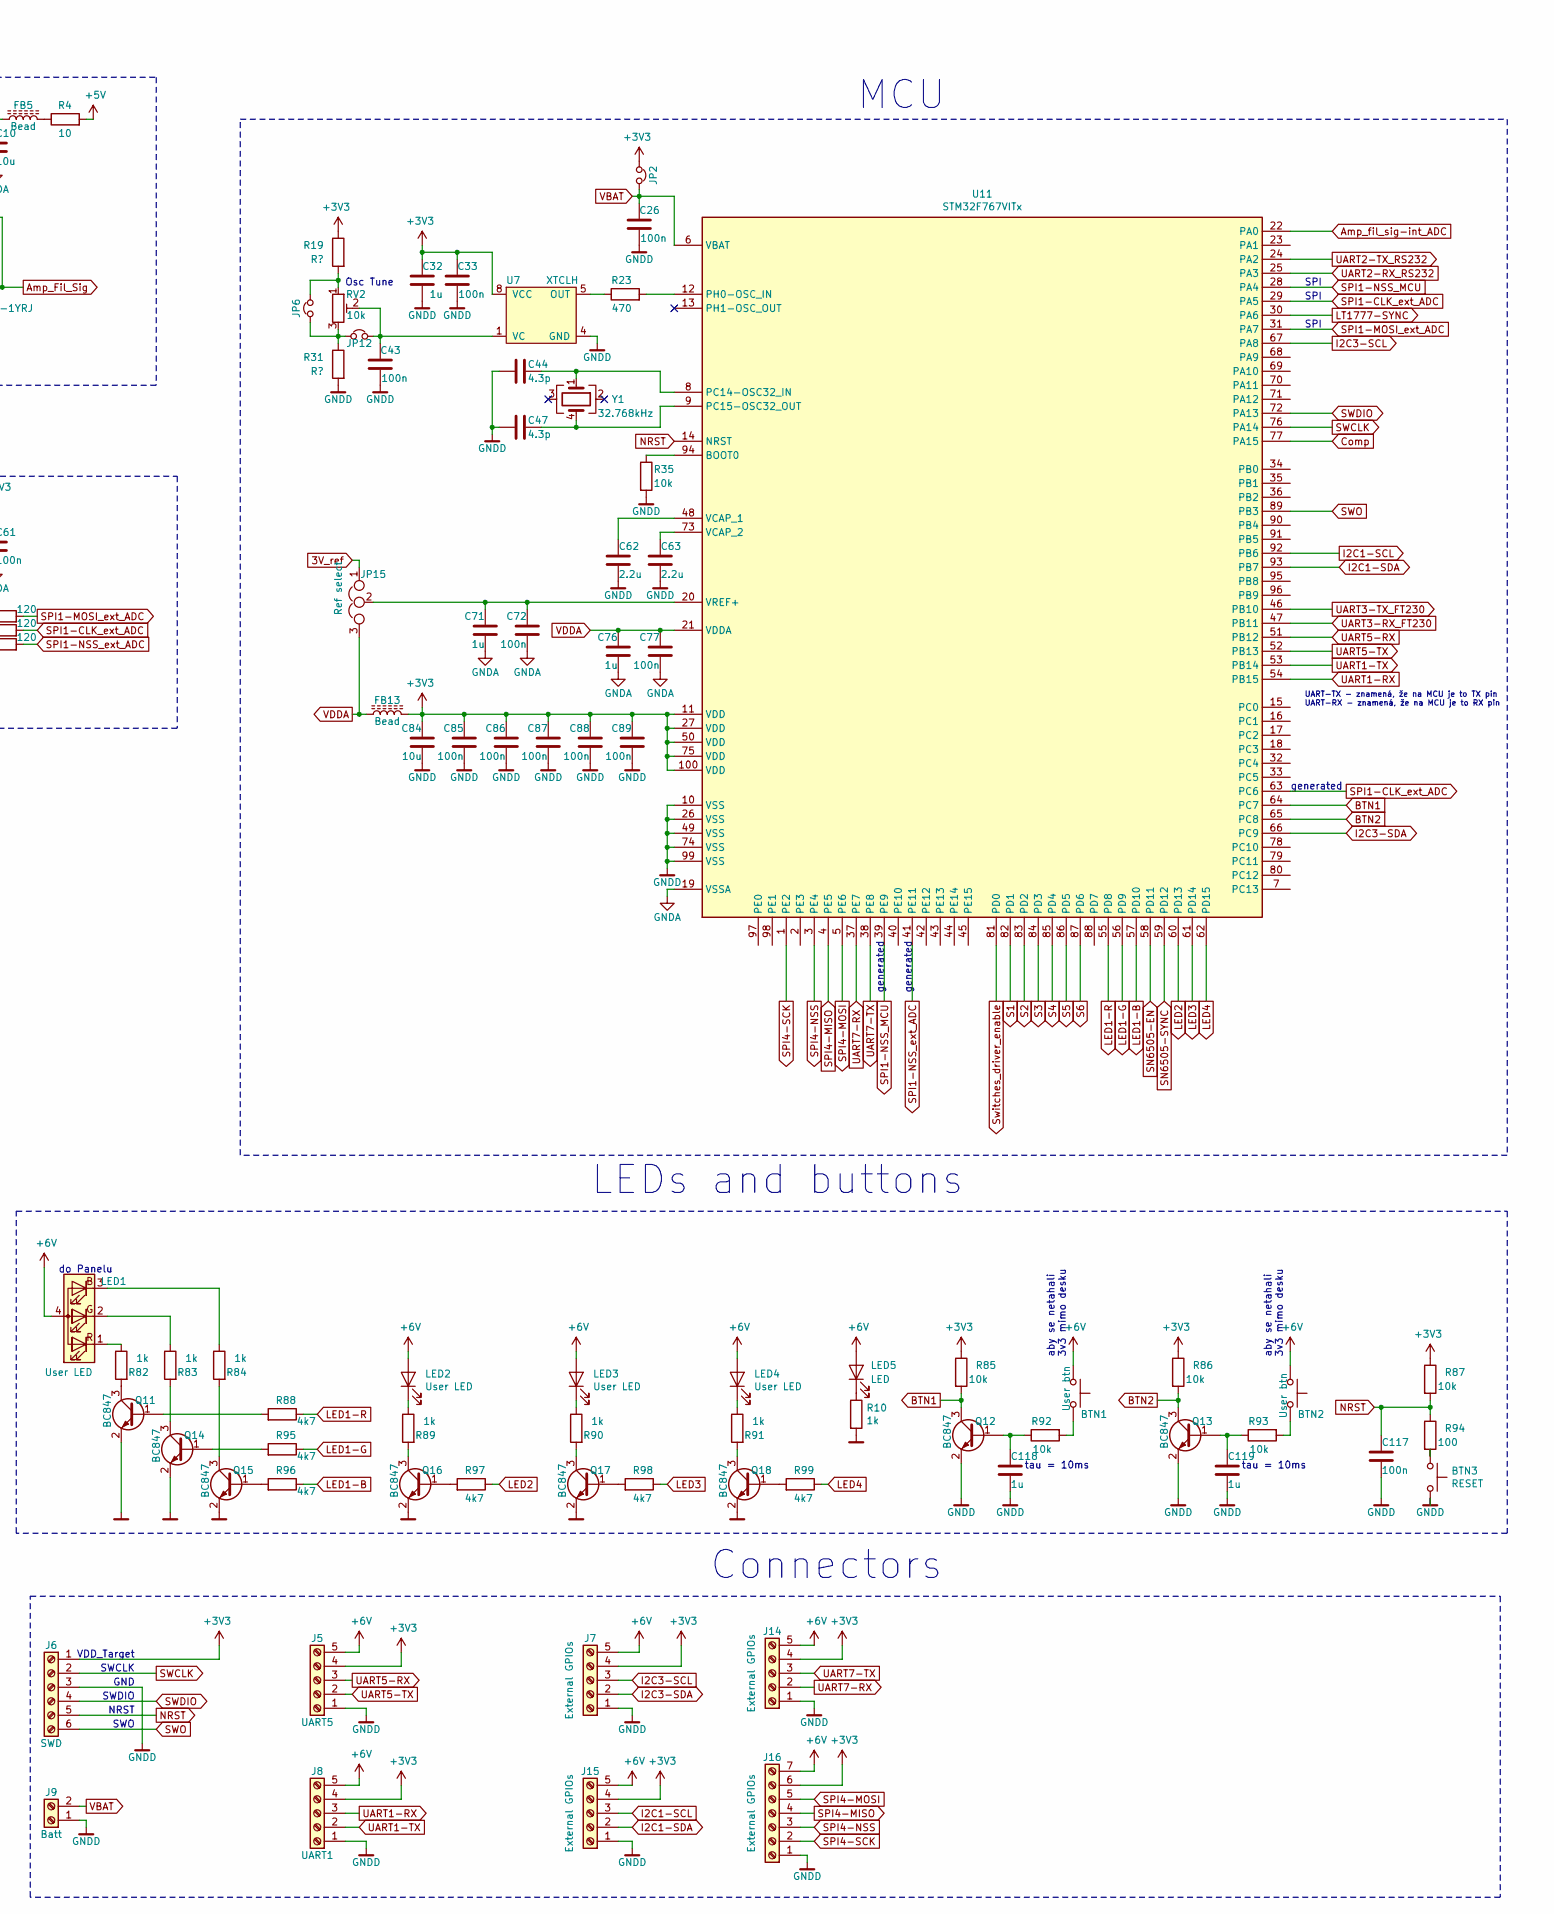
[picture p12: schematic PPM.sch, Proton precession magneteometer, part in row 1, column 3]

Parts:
BTN1, BTN2: User btn; SW_PUSH_6mm
BTN3: RESET; SW_PUSH_6mm
C1, C3, C5, C7, C9, C26, C31, C33, C34, C35, C38, C40, C41, C43, C45, C50, C55, C57, C60, C61, C65, C72, C73, C74, C77, C79, C82, C83, C85, C86, C87, C88, C89, C93, C95, C96, C100, C102, C104, C105, C106, C117, C120, C122, C125, C126, C127, C128, C129, C130, C131: 100n; C0805
C2, C4, C6, C8, C10, C11, C12, C17, C19, C25, C36, C39, C42, C51, C54, C58, C59, C67, C69, C75, C78, C80, C84, C92, C99, C101, C103, C107, C108, C121, C123, C136: 10u; C1206
C13: 100u; CP_EIA-6032-28_Kemet-C
C14, C16: 100u; CP_Radial_D8.0mm_P3.50mm
C15: 1m; CP_Radial_D12.5mm_P5.00mm
C18, C109, C124, C135: 10n; C0805
C20, C32, C56, C71, C76, C118, C119: 1u; C0805
C21, C22, C23, C24, C27, C28, C29, C30: 100n; C_Rect_L7.2mm_W2.5mm_P5.00mm_FKS2_FKP2_MKS2_MKP2
C37: 100u tantal; CP_EIA-7343-20_Kemet-V
C44, C47: 4.3p; C0805
C46: 100u tantal; CP_EIA-6032-28_Kemet-C
C48, C49: 100p; C0805
C52: 470u; CP_Radial_D10.0mm_P5.00mm
C53: 2200p; C0805
C62, C63: 2.2u; C1206
C64: 470n; C0805
C66, C97, C98: 47u; CP_EIA-6032-28_Kemet-C
C68: 10p; C0805
C90: 1m; CP_Radial_D10.0mm_P5.00mm
C94: 1n; C0805
C110: 470u; CP_Radial_D8.0mm_P3.50mm
C132, C133: 47p; C0805
C134: 4n7/2kV; C1210
D1: 15V; D_SOD-123
D2: Transil/27V; D_SMC
D3: MBRS1100; D_SMB
D4, D5: 3v3; D_SOD-123
D7: zener/4v7; D_SOD-123
D8, D9: BAS86; D_MiniMELF
F1: Fuse; Fuse_Holder-PTF15
FB1, FB2, FB3, FB4, FB5, FB6, FB7, FB8, FB9, FB10, FB11, FB12, FB13, FB14, FB15, FB16, FB17, FB18, FB25: Bead; R0805
FB19, FB20, FB21, FB22, FB23, FB24: bead; R0805
J1: 12V - 24V; TerminalBlock_2pin_Pitch5.08mm
J3: RS232; PinHeader_1x03_P2.54mm_Vertical
J4: USB_B; USB_B_OST_USB-B1HSxx_Horizontal
J5: UART5; PinHeader_1x05_P2.54mm_Vertical
J6: SWD; PinHeader_1x06_P2.54mm_Vertical
J7, J14, J15: External GPIOs; PinHeader_1x05_P2.54mm_Vertical
J8: UART1; PinHeader_1x05_P2.54mm_Vertical
J9: Batt; PinHeader_1x02_P2.54mm_Vertical
J10, J11, J12, J13: hole; Screwh_hole-3.5mm
J16: External GPIOs; PinHeader_1x07_P2.54mm_Vertical
J18, J20, J22: TP; PinHeader_1x01_P2.54mm_Vertical
J19, J21, J23, J24, J25, J26, J27, J28, J29, J30: Shield pad; TestPoint
JP1: LDO-5V_supply; Jumper-3pin-P2.54+SMD
JP2, JP6, JP12: no osc tune; Jumper-2pin-P2.54+SMD
JP3: AMP1_OUT; Jumper-2pin-P2.54+SMD
JP4: Reg_ON; Jumper-2pin-P2.54+SMD
JP5: AMP1_IN; Jumper-2pin-P2.54+SMD
JP7: LDO-3V3_supply; Jumper-3pin-P2.54+SMD
JP8, JP9, JP10, JP11, JP15, JP17, JP18, JP21: Ref select; Jumper-3pin-P2.54+SMD
JP13: SYNC; Jumper-3pin-P2.54+SMD
JP14: AMP2_OUT; Jumper-2pin-P2.54+SMD
JP16: AMP2_IN; Jumper-2pin-P2.54+SMD
JP19: AMP3_IN; Jumper-2pin-P2.54+SMD
JP20: AMP3_OUT; Jumper-2pin-P2.54+SMD
JP22: Driver Enable; Jumper-3pin-P2.54+SMD
L1: 10u; Inductor_SRR1208
L2: 2.2u; Inductor_SRR0604
L3: 220uH; Inductor_12x12mm
L4: 20u; Inductor_SRR1208
LED1: User LED; PinHeader_1x04_P2.54mm_Vertical
LED2, LED3, LED4: User LED; LED-THT-3.0mm
LED5: LED; LED-THT-3.0mm
LED6: RX; LED-THT-3.0mm
LED7: TX; LED-THT-3.0mm
Q1: DMPH4015SSSQ-13; SOIC-8_3.9x4.9mm_P1.27mm
Q2, Q3: ZTX851; TO-92L_Inline
Q11, Q12, Q13, Q14, Q15, Q16, Q17, Q18: BC847; SOT-23
R1, R2, R3, R4, R68: 10; R0805
R5: 27; R1206
R6: 100k; R0805
R7, R22, R35, R42, R45, R48, R62, R63, R65, R66, R85, R86, R87, R92, R93, R112: 10k; R0805
R8: 1k5; R0805
R9, R10, R44, R52, R82, R83, R84, R89, R90, R91, R100, R102: 1k; R0805
R11, R13: 349; R0805
R12, R14: 203; R0805
R15, R17: 4.08k; R0805
R16, R18: 2.37k; R0805
R19, R31: R?; R0805
R20: 120k; R0805
R21: 10M; R0805
R23, R106, R107: 470; R0805
R24, R26: 1.14k; R0805
R25, R27: 662; R0805
R28, R34, R43, R51, R53, R58: 2k2; R0805
R29, R40: 33k; R0805
R30, R57: 2.2; R1206
R32: 12k; R0805
R33: 40.2k; R0805
R36: 10.5k; R0805
R37, R59: 470; R1206
R38: 5k1; R0805
R39, R64, R101, R103: 47; R0805
R41: 22k; R0805
R46, R47, R49: 120; R0805
R54: 680k; R0805
R56: 18k; R0805
R61: 15k; R0805
R88, R95, R96, R97, R98, R99, R108: 4k7; R0805
R94, R109, R110: 100; R0805
R104, R105: 27; R0805
R111: 0; R0805
RV1: Varistor/27V; B72210S0170K101
RV2: 10k; Potentiometer_Piher_PT-10-V10_Vertical_Hole
RV3, RV4: Varistor; SOT-23
T1: Filter; B82792C2
T2: 78253_55JC
U1: TPS7A4700; QFN-20-1EP_5x5mm_P0.65mm_EP3.35x3.35mm
U2, U10, U12, U17, U19: LT1677; SO-8_3.9x4.9mm_P1.27mm
U3, U4, U5, U6: ADA4841-1YRJ; SOT-23-6
U7: XTCLH
U8: TL1963A-33KTTR; TO-263-5_TabPin3
U9: LT1777; STC_SOP-16_3.9x9.9mm_P1.27mm
U11: STM32F767VITx; LQFP-100_14x14mm_P0.5mm
U13: MAX6043; SOT-23-6
U14: MAX11100; UMAX-10
U15: ADCMP609; MSOP-8_3x3mm_P0.65mm
U16: LTC6655; MSOP-8_3x3mm_P0.65mm
U18: MCP1501-30E_SN; SOIC-8_3.9x4.9mm_P1.27mm
U20: MCP6021R; SOT-23-5
U21: SN74ACT244-Q1; TSSOP-20_4.4x6.5mm_P0.65mm
U22: MAX3227EE; SSOP-16_5.3x6.2mm_P0.65mm
U23: FT230XS; SSOP-16_3.9x4.9mm_P0.635mm
U24: ADuM226N; SOIC-8_7.5x5.85mm_P1.27mm
U25: SN6505; SOT-23-6
Y1: 32.768kHz; Crystal-ABS25

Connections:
2.5V_ref_1: C67.1, JP8.3, JP9.3, JP10.3, JP11.3, JP17.3, JP18.3, JP21.3, R34.2, R39.2
3v3_izolated: C122.2, C125.2, C128.2, FB17.2, U22.12 (FORCEON), U22.15 (VCC), U22.16 (~FORCEOFF), U24.8 (VDD2)
4.096V_ref: C74.1, C80.1, R42.1, U13.5 (OUTF), U13.6 (OUTS), U14.6 (REF)
+3V3: C32.1, C33.1, C41.1, C42.1, C61.1, C84.1, C85.1, C86.1, C87.1, C88.1, C89.1, C120.1, C121.1, C131.2, C135.2, C136.2, FB13.1, FB15.2, J5.4, J6.1, J7.4, J8.4, J14.4, J15.4, J16.6, JP2.1, LED6.2 (A), LED7.2 (A), R19.1, R85.1, R86.1, R87.1, T2.5, U7.8 (VCC), U8.4 (OUT), U8.5 (Sense), U11.11 (VDD), U11.27 (VDD), U11.50 (VDD), U11.75 (VDD), U11.100 (VDD), U14.3 (DVDD), U23.3 (VCCIO), U23.10 (3V3OUT), U23.11 (~RESET), U23.12 (VCC), U24.1 (VDD1), U25.2 (VCC)
+5V: C11.1, C12.1, C13.1, C73.1, C92.1, C93.1, C95.1, FB1.2, FB6.2, FB7.2, FB8.2, FB9.2, FB11.2, FB14.2, FB16.2, R1.2, R2.2, R3.2, R4.2, U1.1 (OUT), U1.3 (Sense), U1.20 (OUT), U13.4 (IN), U16.1 (~SHDN), U16.2 (VIN), U18.1 (VDD), U18.3 (~SHDN)
+6V: BTN1.1, BTN2.1, C52.1, J5.5, J7.5, J8.5, J14.5, J15.5, J16.7, JP1.1, JP7.1, L4.2, LED1.4 (A), LED2.2 (A), LED3.2 (A), LED4.2 (A), LED5.2 (A)
+12V: C15.1, C16.1, C17.1, C18.1, D1.1 (K), JP1.3, JP4.1, JP7.3, Q1.1 (S), Q1.2 (S), Q1.3 (S), R6.1; also elsewhere on the board
Amp_Fil_Sig: C24.2, C64.1, C65.2, C105.2, R18.1, U6.1
Amp_Sig: JP3.2, JP14.2, JP20.1, R11.1
Amp_fil_sig-int_ADC: C109.1, R64.2, U11.22 (PA0)
BTN1: Q12.3 (C), R85.2, U11.64 (PC7)
BTN2: Q13.3 (C), R86.2, U11.65 (PC8)
Comp: D5.1 (K), R44.1, U11.77 (PA15)
GNDA: BTN3.2, C1.2, C2.2, C3.2, C4.2, C5.2, C6.2, C7.2, C8.2, C9.2, C10.2, C11.2, C12.2, C13.2, C14.2, C15.2, C16.2, C17.2, C18.2, C19.2, C20.2, C26.2, C31.2, C32.2, C33.2, C35.2, C37.2, C38.2, C39.2, C40.2, C41.2, C42.2, C43.2, C44.2, C45.2, C46.2, C47.2, C48.2, C49.2, C50.2, C51.2, C52.2, C53.2, C54.2, C55.2, C57.2, C58.2, C59.2, C60.2, C61.2, C62.2, C63.2, C66.2, C67.2, C71.2, C72.2, C73.2, C74.2, C75.1, C76.2, C77.2, C78.2, C79.2, C80.2, C82.1, C83.1, C84.2, C85.2, C86.2, C87.2, C88.2, C89.2, C90.2, C92.2, C93.2, C94.2, C95.2, C96.2, C97.2, C98.2, C99.2, C100.2, C101.2, C102.2, C103.2, C106.2, C107.2, C108.1, C109.2, C110.2, C117.2, C118.2, C119.2, C120.2, C121.2, C131.1, C132.2, C133.2, C134.1, C135.1, C136.1, D2.2 (A2), D3.2 (A), D4.2 (A), D5.2 (A), FB18.1, J1.1, J4.4 (GND), J5.1, J6.3, J7.1, J8.1, J9.1, J14.1, J15.1, J16.1, J18.1, J19.1, J20.1, J21.1, J22.1, J23.1, J24.1, J25.1, J26.1, J27.1, J28.1, J29.1, J30.1, JP13.3, JP22.1, Q11.2 (E), Q12.2 (E), Q13.2 (E), Q14.2 (E), Q15.2 (E), Q16.2 (E), Q17.2 (E), Q18.2 (E), R9.2, R10.2, R22.2, R29.2, R30.2, R31.2, R35.2, R36.2, R41.2, R48.2, R54.2, R56.2, R59.2, R65.1, R112.1, RV1.2, U1.6 (3P2V), U1.7 (GND), U1.10 (0P4V), U1.21 (GND), U2.4 (V-), U3.2 (V-), U4.2 (V-), U5.2 (V-), U6.2 (V-), U7.4 (GND), U8.3 (GND), U9.1 (GND), U9.7 (SGND), U9.8 (GND), U9.9 (GND), U9.16 (GND), U10.4 (V-), U11.10 (VSS), U11.19 (VSSA), U11.26 (VSS), U11.49 (VSS), U11.74 (VSS), U11.99 (VSS), U12.4 (V-), U13.2 (GND), U14.2 (DGND), U14.4 (AGND), U14.8 (AGND), U15.6 (V-), U16.3 (GND), U16.4 (GND), U16.5 (GND), U16.8 (GND), U17.4 (V-), U18.2 (GND), U18.4 (GND), U18.5 (GND), U18.6 (GND), U19.4 (V-), U20.2 (V-), U21.10 (GND), U23.5 (GND), U23.13 (GND), U24.4 (GND1), U25.4 (GND); also elsewhere on the board
GNDREF: C122.1, C123.1, C124.1, C125.1, C128.1, C129.1, C130.1, C134.2, D7.2 (A), RV3.2, RV4.2, T1.4, T2.2, U22.14 (GND), U24.5 (GND2)
I2C1-SCL: J15.3, U11.92 (PB6)
I2C1-SDA: J15.2, U11.93 (PB7)
I2C3-SCL: J7.3, U11.67 (PA8)
I2C3-SDA: J7.2, U11.66 (PC9)
LED1-B: R96.1, U11.57 (PD10)
LED1-G: R95.1, U11.56 (PD9)
LED1-R: R88.1, U11.55 (PD8)
LED2: R97.1, U11.60 (PD13)
LED3: R98.1, U11.61 (PD14)
LED4: R99.1, U11.62 (PD15)
LT1777-SYNC: JP13.1, U11.30 (PA6)
NRST: C117.1, J6.5, R87.2, R94.1, U11.14 (NRST)
unnamed: BTN1.2, R92.2
unnamed: BTN2.2, R93.2
unnamed: BTN3.1, R94.2
unnamed: C1.1, C2.1, FB1.1, R5.1, R7.1, U2.7 (V+)
unnamed: C3.1, C4.1, FB2.1, U3.6 (V+)
unnamed: C5.1, C6.1, FB3.1, U4.6 (V+)
unnamed: C7.1, C8.1, FB4.1, U5.6 (V+)
unnamed: C9.1, C10.1, FB5.1, U6.6 (V+)
unnamed: C14.1, R5.2, R8.1
unnamed: C19.1, JP1.2, U1.13 (EN), U1.15 (IN), U1.16 (IN)
unnamed: C20.1, U1.14 (NR)
unnamed: C21.1, C27.1, R11.2, R24.1
unnamed: C21.2, R12.1, R15.1, U3.1
unnamed: C22.1, C28.1, R12.2, R25.1
unnamed: C22.2, R13.1, R16.1, U4.1
unnamed: C23.1, C29.1, R13.2, R26.1
unnamed: C23.2, R14.1, R17.1, U5.1
unnamed: C24.1, C30.1, R14.2, R27.1
unnamed: C25.1, R21.1, U2.2 (-)
unnamed: C25.2, Q2.3 (C), R8.2, R20.1
unnamed: C27.2, R15.2, U3.4 (-)
unnamed: C28.2, R16.2, U4.4 (-)
unnamed: C29.2, R17.2, U5.4 (-)
unnamed: C30.2, R18.2, U6.4 (-)
unnamed: C31.1, R7.2, R22.1, U2.3 (+)
unnamed: C34.1, Q2.2 (B), R20.2, R29.1
unnamed: C34.2, JP5.1
unnamed: C35.1, C46.1, L3.2, L4.1, R33.1, U9.4 (VCC)
unnamed: C36.1, JP3.1, R21.2, U2.6
unnamed: C36.2, R28.2
unnamed: C37.1, C38.1, JP4.2, U9.10 (VIN)
unnamed: C39.1, C40.1, JP7.2, U8.1 (~SHDN), U8.2 (IN)
unnamed: C43.1, JP12.1, RV2.2, U7.1 (VC)
unnamed: C44.1, U11.8 (PC14-OSC32_IN), Y1.1
unnamed: C45.1, R108.1, R112.2, U23.15 (CBUS0)
unnamed: C47.1, U11.9 (PC15-OSC32_OUT), Y1.4
unnamed: C48.1, U9.3 (~SHDN)
unnamed: C49.1, R32.1, U9.14 (VC)
unnamed: C50.1, C51.1, FB6.1, R37.1, R38.2, R40.1, U10.7 (V+)
unnamed: C53.1, R32.2
unnamed: C54.1, C55.1, FB7.1, U12.7 (V+)
unnamed: C56.1, R39.1, U12.6
unnamed: C56.2, R34.1, U12.2 (-)
unnamed: C57.1, C58.1, FB8.1, U15.1 (V+), U15.4 (Sdn)
unnamed: C59.1, C60.1, FB9.1, U14.7 (AVDD)
unnamed: C62.1, U11.48 (VCAP_1)
unnamed: C63.1, U11.73 (VCAP_2)
unnamed: C64.2, C82.2, R43.1, U15.2 (+)
unnamed: C65.1, R45.2, U14.5 (AIN)
unnamed: C66.1, R38.1, R41.1, U10.3 (+)
unnamed: C68.2, Q3.3 (C), R37.2, U10.2 (-)
unnamed: C69.1, Q3.2 (B), R40.2, R56.1
unnamed: C69.2, JP16.2
unnamed: C71.1, C72.1, JP15.2, U11.20 (VREF+)
unnamed: C75.2, R42.2, R45.1, R48.1
unnamed: C78.1, C79.1, FB11.1, U17.7 (V+)
unnamed: C83.2, R53.1, U15.3 (-)
unnamed: C90.1, R57.2
unnamed: C96.1, C97.1, R58.1, U16.6 (VOUT_s), U16.7 (VOUT_f)
unnamed: C98.1, C99.1, R58.2, U12.3 (+), U17.3 (+)
unnamed: C100.1, C101.1, FB14.1, U19.7 (V+)
unnamed: C102.1, C103.1, FB15.1, U20.5 (V+)
unnamed: C104.1, JP19.2
unnamed: C104.2, R66.1, U19.3 (+)
unnamed: C105.1, R62.2, U20.3 (+)
unnamed: C106.1, C107.1, FB16.1, U21.20 (VCC)
unnamed: C108.2, R61.2, R62.1, R65.2
unnamed: C110.1, R68.1
unnamed: C118.1, Q12.1 (B), R92.1
unnamed: C119.1, Q13.1 (B), R93.1
unnamed: C123.2, C124.2, D7.1 (K), D8.1 (K), D9.1 (K), FB17.1
unnamed: C126.1, U22.2 (C1+)
unnamed: C126.2, U22.4 (C1-)
unnamed: C127.1, U22.5 (C2+)
unnamed: C127.2, U22.6 (C2-)
unnamed: C129.2, U22.3 (V+)
unnamed: C130.2, U22.7 (V-)
unnamed: C132.1, J4.2 (D-), R104.2
unnamed: C133.1, J4.3 (D+), R105.2
unnamed: D1.2 (A), Q1.4 (G), R6.2, R9.1
unnamed: D2.1 (A1), L1.2, Q1.5 (D), Q1.6 (D), Q1.7 (D), Q1.8 (D)
unnamed: D3.1 (K), L2.2, L3.1, U9.5 (VD)
unnamed: D8.2 (A), T2.3
unnamed: D9.2 (A), T2.1
unnamed: F1.1, L1.1, RV1.1
unnamed: F1.2, J1.2
unnamed: FB2.2, R1.1
unnamed: FB3.2, R2.1
unnamed: FB4.2, R3.1
unnamed: FB5.2, R4.1
unnamed: FB10.1, FB12.1, JP17.2
unnamed: FB10.2, R43.2
unnamed: FB12.2, R53.2
unnamed: FB18.2, J4.5 (Shield)
unnamed: FB19.1, U21.14 (1Y3), U21.16 (1Y2), U21.18 (1Y1)
unnamed: FB20.1, U21.12 (1Y4)
unnamed: FB21.1, U21.9 (2Y1)
unnamed: FB22.1, U21.7 (2Y2)
unnamed: FB23.1, U21.5 (2Y3)
unnamed: FB24.1, U21.3 (2Y4)
unnamed: FB25.1, J4.1 (VBUS)
unnamed: FB25.2, R108.2
unnamed: J3.1, T1.5
unnamed: J3.2, R103.1
unnamed: J3.3, R101.1
unnamed: JP6.1, R19.2, RV2.1
unnamed: JP8.2, R24.2, U3.3 (+)
unnamed: JP9.2, R25.2, U4.3 (+)
unnamed: JP10.2, R26.2, U5.3 (+)
unnamed: JP11.2, R27.2, U6.3 (+)
unnamed: JP6.2, JP12.2, R31.1, RV2.3
unnamed: JP13.2, U9.12 (SYNC)
unnamed: JP18.2, R61.1
unnamed: JP20.2, R63.2, U19.6
unnamed: JP21.2, R66.2
unnamed: JP22.2, U21.1 (1~OE), U21.19 (2~OE)
unnamed: L2.1, U9.6 (VSW)
unnamed: LED1.1 (RK), R82.1
unnamed: LED1.2 (GK), R83.1
unnamed: LED1.3 (BK), R84.1
unnamed: LED2.1 (K), R89.1
unnamed: LED3.1 (K), R90.1
unnamed: LED4.1 (K), R91.1
unnamed: LED5.1 (K), R10.1
unnamed: LED6.1 (K), R106.2
unnamed: LED7.1 (K), R107.2
unnamed: Q2.1 (E), R28.1, R30.1
unnamed: Q3.1 (E), R51.1, R57.1, R59.1
unnamed: Q11.1 (B), R88.2
unnamed: Q11.3 (C), R82.2
unnamed: Q14.1 (B), R95.2
unnamed: Q14.3 (C), R83.2
unnamed: Q15.1 (B), R96.2
unnamed: Q15.3 (C), R84.2
unnamed: Q16.1 (B), R97.2
unnamed: Q16.3 (C), R89.2
unnamed: Q17.1 (B), R98.2
unnamed: Q17.3 (C), R90.2
unnamed: Q18.1 (B), R99.2
unnamed: Q18.3 (C), R91.2
unnamed: R23.1, U7.5 (OUT)
unnamed: R23.2, U11.12 (PH0-OSC_IN)
unnamed: R33.2, R36.1, U9.13 (FB)
unnamed: R35.1, U11.94 (BOOT0)
unnamed: R44.2, U15.7
unnamed: R46.1, U14.1 (DOUT)
unnamed: R47.1, U14.10 (SCLK)
unnamed: R49.1, U14.9 (~CS)
unnamed: R52.2, U15.8
unnamed: R54.1, U15.5 (HYS)
unnamed: R63.1, R68.2, U19.2 (-)
unnamed: R64.1, U20.1, U20.4 (-)
unnamed: R100.2, U23.1 (TXD)
unnamed: R101.2, T1.8
unnamed: R102.2, U23.4 (RXD)
unnamed: R103.2, T1.6
unnamed: R104.1, U23.9 (USBDM)
unnamed: R105.1, U23.8 (USBDP)
unnamed: R106.1, U23.14 (CBUS1)
unnamed: R107.1, U23.7 (CBUS2)
unnamed: R109.1, U24.2 (Voa)
unnamed: R110.1, U24.3 (Vib)
unnamed: R111.1, U25.6 (CLK)
unnamed: RV3.1, T1.1, U22.8 (RIN)
unnamed: RV4.1, T1.3, U22.13 (DOUT)
unnamed: T2.4, U25.3 (D2)
unnamed: T2.6, U25.1 (D1)
unnamed: U22.9 (ROUT), U24.7 (Via)
unnamed: U22.11 (DIN), U24.6 (Vob)
S1: U11.82 (PD1), U21.2 (1A1), U21.4 (1A2), U21.6 (1A3)
S1_FET: FB19.2; also elsewhere on the board
S2: U11.83 (PD2), U21.17 (2A4)
S2_FET: FB24.2; also elsewhere on the board
S3: U11.84 (PD3), U21.15 (2A3)
S3_FET: FB23.2; also elsewhere on the board
S4: U11.85 (PD4), U21.8 (1A4)
S4_FET: FB20.2; also elsewhere on the board
S5: U11.86 (PD5), U21.11 (2A1)
S5_FET: FB21.2; also elsewhere on the board
S6: U11.87 (PD6), U21.13 (2A2)
S6_FET: FB22.2; also elsewhere on the board
SN6505-EN: U11.58 (PD11), U25.5 (EN)
SN6505-SYNC: R111.2, U11.59 (PD12)
SPI1-CLK_ext_ADC: R47.2, U11.29 (PA5), U11.63 (PC6)
SPI1-MOSI_ext_ADC: R46.2, U11.31 (PA7)
SPI1-NSS_MCU: U11.28 (PA4), U11.39 (PE9)
SPI1-NSS_ext_ADC: R49.2, U11.41 (PE11)
SPI4-MISO: J16.4, U11.4 (PE5)
SPI4-MOSI: J16.5, U11.5 (PE6)
SPI4-NSS: J16.3, U11.3 (PE4)
SPI4-SCK: J16.2, U11.1 (PE2)
SWCLK: J6.2, U11.76 (PA14)
SWDIO: J6.4, U11.72 (PA13)
SWO: J6.6, U11.89 (PB3)
Sig: JP5.2, JP16.1, JP19.1; also elsewhere on the board
Switches_driver_enable: JP22.3, U11.81 (PD0)
UART1-RX: J8.3, U11.54 (PB15)
UART1-TX: J8.2, U11.53 (PB14)
UART2-RX_RS232: R109.2, U11.25 (PA3)
UART2-TX_RS232: R110.2, U11.24 (PA2)
UART3-RX_FT230: R100.1, U11.47 (PB11)
UART3-TX_FT230: R102.1, U11.46 (PB10)
UART5-RX: J5.3, U11.51 (PB12)
UART5-TX: J5.2, U11.52 (PB13)
UART7-RX: J14.2, U11.37 (PE7)
UART7-TX: J14.3, U11.38 (PE8)
VBAT: C26.1, J9.2, JP2.2, U11.6 (VBAT)
VDDA: C76.1, C77.1, FB13.2, JP15.3, U11.21 (VDDA)
~Comp: D4.1 (K), R52.1

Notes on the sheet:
GNDD - MCU GNDA - OpAmp circuits SGND - buck converter GNDPWR - power connections
Power supply
connector for switching system
UART - USB communication
ADC
BP filter
Amplifiers
Shift sig for MCU ADC
VOUT = 1.4V + 0.4V + 3.2V= 5V
1V_ref
1 : 1.31
UART - RS232 communication
RS232_RX
RS232_TX
2.048V_ref
VDD_Target
SWCLK
GND
SWDIO
NRST
SWO
if R not soldered device uses internal clock
generated
SPI
Comparator
MCU
Connectors
UART-TX - znamená, že na MCU je to TX pin UART-RX - znamená, že na MCU je to RX pin
Osc Tune
do Panelu
tau = 10ms
LEDs and buttons
aby se netahali 3v3 mimo desku
DB9_Female - pin2
DB9_Female - pin3
DB9_Female - pin5
Used Amplifier

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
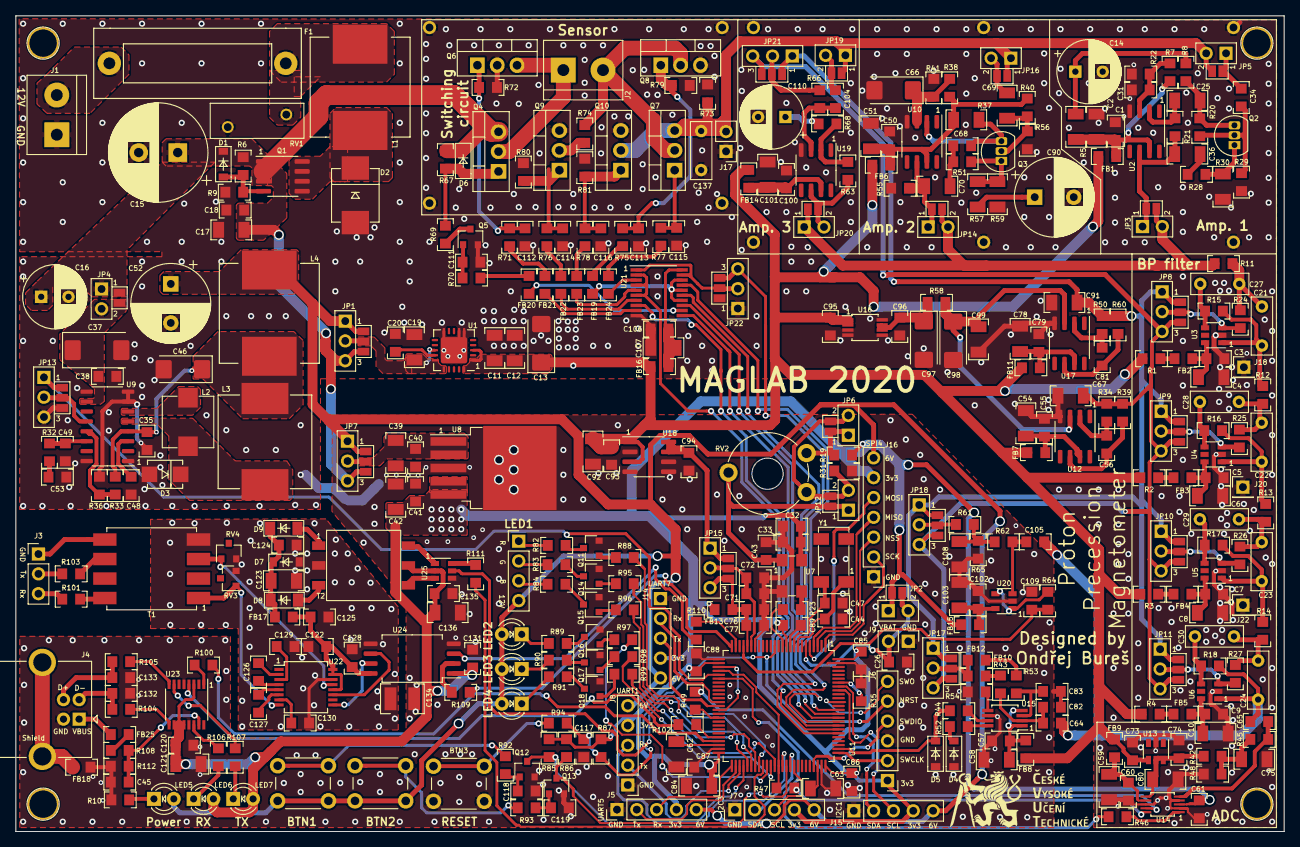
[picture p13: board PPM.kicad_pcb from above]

Board: 2 copper layers, 162.5 x 104.5 mm, 400 parts (0 on the bottom side), 253 nets.

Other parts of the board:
C70: 22u; C1206
C81: 1u; C0805
C91: 10u; C1206
C111: 10n; C0805
C112, C113, C114, C115, C116: 100n; C0805
C137: C_res; C_Rect_L7.2mm_W2.5mm_P5.00mm_FKS2_FKP2_MKS2_MKP2
D6: 15V; D_SOD-123
J2: PPM_sensor; TerminalBlock_2pin_Pitch5.08mm
J17: C ext; PinHeader_1x02_P2.54mm_Vertical
Q4: IRF9640; TO-220-3_Vertical
Q5: BC847; SOT-23
Q6, Q7, Q9, Q10: IRF740; TO-220-3_Vertical
Q8: IRF640; TO-220-3_Vertical
R50, R67: 2k2; R0805
R55: 47k; R0805
R60: 47; R0805
R69: 1k; R0805
R70: 4k7; R0805
R71, R75, R76, R77, R78: 470; R0805
R72, R73, R79, R80, R81: 100k; R0805
R74: 10k; R0805

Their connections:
+12V: D6.1, Q4.3, R67.1; also elsewhere on the board
GNDA: C91.2, C111.2, C112.2, C113.2, C114.2, C115.2, C116.2, C137.2, J17.1, Q5.2, Q6.2, Q8.3, Q9.3, Q10.3, R55.2, R72.2, R73.2, R79.2, R80.2, R81.2; also elsewhere on the board
unnamed: C111.1, Q5.1, R70.2
unnamed: C112.1, Q6.1, R71.2, R72.1
unnamed: C113.1, Q8.1, R75.2, R79.1
unnamed: C114.1, Q9.1, R76.2, R80.1
unnamed: C115.1, Q7.1, R77.2
unnamed: C116.1, Q10.1, R78.2, R81.1
unnamed: D6.2, Q4.1, R67.2, R69.1
unnamed: J2.1, Q4.2, Q6.3
unnamed: J2.2, Q7.2, Q8.2, R74.1
unnamed: Q5.3, R69.2
unnamed: Q9.2, R74.2
S1_FET: R75.1; also elsewhere on the board
S2_FET: R77.1; also elsewhere on the board
S3_FET: R78.1; also elsewhere on the board
S4_FET: R70.1; also elsewhere on the board
S5_FET: R71.1; also elsewhere on the board
S6_FET: R76.1; also elsewhere on the board
Sig: C137.1, J17.2, Q7.3, Q10.2, R73.1; also elsewhere on the board

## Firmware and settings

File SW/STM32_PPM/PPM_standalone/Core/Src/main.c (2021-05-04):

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

/* Includes ------------------------------------------------------------------*/
#include "main.h"

/* USER CODE BEGIN Includes */
#include "float.h"
#include "string.h"
#include "stdio.h"
#include <stdlib.h>
#include "config.h"
#include "communication.h"
#include "delay.h"
#include "switchingCircuitController.h"

/* USER CODE END Includes */

/* USER CODE BEGIN PD */
#define TIMER  TIM4
/* USER CODE END PD */

ADC_HandleTypeDef hadc1;
DMA_HandleTypeDef hdma_adc1;

I2C_HandleTypeDef hi2c1;
I2C_HandleTypeDef hi2c3;

SPI_HandleTypeDef hspi1;
SPI_HandleTypeDef hspi4;
DMA_HandleTypeDef hdma_spi1_rx;

TIM_HandleTypeDef htim1;
TIM_HandleTypeDef htim2;
TIM_HandleTypeDef htim3;
TIM_HandleTypeDef htim4;
TIM_HandleTypeDef htim5;
TIM_HandleTypeDef htim6;
TIM_HandleTypeDef htim8;
DMA_HandleTypeDef hdma_tim2_ch1;

UART_HandleTypeDef huart7;
UART_HandleTypeDef huart1;
UART_HandleTypeDef huart2;
UART_HandleTypeDef huart3;

/* USER CODE BEGIN PV */

uint8_t filledBuffersExtADC = 0;
uint8_t filledBuffersIntADC = 0;
uint32_t samplesTotal = 44100 * 2;

uint32_t IC_Value1 = 0;
uint32_t IC_Value2 = 0;
uint32_t difference = 0;
uint32_t frequency = 0;
uint8_t firstCapturedSample = 0;  // 0- not captured, 1- captured


/* USER CODE END PV */

void SystemClock_Config(void);
static void MX_GPIO_Init(void);
static void MX_DMA_Init(void);
static void MX_ADC1_Init(void);
static void MX_SPI1_Init(void);
static void MX_TIM1_Init(void);
static void MX_TIM2_Init(void);
static void MX_TIM3_Init(void);
static void MX_TIM4_Init(void);
static void MX_TIM8_Init(void);
static void MX_USART1_UART_Init(void);
static void MX_USART2_UART_Init(void);
static void MX_USART3_UART_Init(void);
static void MX_I2C1_Init(void);
static void MX_I2C3_Init(void);
static void MX_SPI4_Init(void);
static void MX_TIM5_Init(void);
static void MX_UART7_Init(void);
static void MX_TIM6_Init(void);
/**
 * @brief  The application entry point.
 * @retval int
 */
int main(void) {
	/* MCU Configuration--------------------------------------------------------*/

	/* Reset of all peripherals, Initializes the Flash interface and the Systick. */
	HAL_Init();

	/* Configure the system clock */
	SystemClock_Config();

	/* Initialize all configured peripherals */
	MX_GPIO_Init();
	MX_DMA_Init();
	MX_ADC1_Init();
	MX_SPI1_Init();
	MX_TIM1_Init();
	MX_TIM2_Init();
	MX_TIM3_Init();
	MX_TIM4_Init();
	MX_TIM8_Init();
	MX_USART1_UART_Init();
	MX_USART2_UART_Init();
	MX_USART3_UART_Init();
	MX_I2C1_Init();
	MX_I2C3_Init();
	MX_SPI4_Init();
	MX_TIM5_Init();
	MX_UART7_Init();
	MX_TIM6_Init();
	/* USER CODE BEGIN 2 */
	initialization();
	HAL_Delay(10);
	/* USER CODE END 2 */

	/* Infinite loop */
	/* USER CODE BEGIN WHILE */
	while (1) {
		/* USER CODE END WHILE */

		/* USER CODE BEGIN 3 */

		//parse text every time before polarization
		if (newDataInBuffer()) {
			parseText(huart3);
		}

		// if new measurement technique was updated - change state regarding to the update
		if (stateCanBeUpdated()) {
			updateState();
		}

		// normal mode with polarization
		if (ploarizationCanRun()) {
			runPolarizationSequence();
			if (dataReadyToSendBeforeMeasurement()) {
				sendMeasuredData(huart3);
			}
		}

		// measurement
		if (measurementCanRun()) {
			runMeasurementMethod();
		}

		//
		if (dataReadyToSendAfterMeasurement()) {
			sendMeasuredData(huart3);
		}
		if (isWaitingForSync()) {
			set_LED1(0, 0, 1);
		}

		// idle state - if no method is active and there are no data to be sent
		if (stateIsIdle()) {
			set_LED1(0, 0, 0);
		}

	}

	/* USER CODE END 3 */
}

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
/* USER CODE BEGIN 4 */


void initialization() {
	//setStateToMeasureOnlyNoPolarization();
	HAL_UART_Receive_IT(&huart3, buffer_uart_rx, 1);	// start listening to commands
	HAL_TIM_Base_Start_IT(&htim5); 						// start timer for delay measuring
	switchingCircuitIdle();
	timeIndex = 0;
	remainingPolarizationTime = 0;
	remainingTimeToNextMeasurement = 0;
	set_LED1(0, 0, 0);
	setStateToDefault();								// set state in order to polarize with period 5 seconds
}


void runMeasurementMethod() {
	//there is no need to run measurement sequence, when the mode is "measureOnSync"
	if(!isModeMeasureOnSync()){
		runMeasurementSequence();
	}
	//if measurement method is set, run it
	if ((state.remainingMeasurements > 0) || (state.remainingMeasurements == -1) && ((state.extAdcActiveState == 1) || (state.intAdcActiveState == 1) || (state.compActiveState == 1))) {
		// check, if there isn't new user update before starting measurement
		if (newDataInBuffer()) {
			parseText(huart3);
		}
		// also update the state
		if (stateCanBeUpdated()) {
			updateState();
		}
		if (state.extAdcActiveState == 1) {
			measureWithExtADC();
		}
		if (state.intAdcActiveState == 1) {
			measureWithIntADC();
		}
		if (state.compActiveState == 1) {
			measureWithComp();
		}
	}
}


void measureWithExtADC() {
	// visualise with green color
	// Start SPI communication over DMA
	HAL_SPI_Receive_DMA(&hspi1, buffer_extAdc_1.uint8, samplesPerPeriod);
	//turn on timers
	HAL_TIM_PWM_Start_IT(&htim1, TIM_CHANNEL_1);	// SPI -  MCU NSS
	HAL_TIM_PWM_Start_IT(&htim1, TIM_CHANNEL_2); 	// SPI -  External ADC NSS
	HAL_TIM_PWM_Start_IT(&htim8, TIM_CHANNEL_1);	// SPI -  CLK
	set_LED2(1);
	set_LED1(0, 1, 0); // v
	state.extAdcMeasuring = 1;
	//keep "preparedToRunMeasurementPhase" low -> when mode is 1, in interrupt it can be set to high...
	state.preparedToRunMeasurementPhase = 0;
}

void measureWithIntADC() {
	// visualise with green color
	set_LED1(0, 1, 0);
	//start ADC
	HAL_ADC_Start_DMA(&hadc1, (uint32_t*) &buffer_intAdc_1.uint16, samplesPerPeriod);
	// start timer
	HAL_TIM_Base_Start_IT(&htim6);
	set_LED3(1);
	state.intAdcMeasuring = 1;
	//keep "preparedToRunMeasurementPhase" low -> when mode is 1, in interrupt it can be set to high...
	state.preparedToRunMeasurementPhase = 0;
}

void measureWithComp() {
	// visualise with green color
	set_LED1(0, 1, 0);
	// run the timer 4001 - 2 seconds for 2 kHz
	HAL_TIM_IC_Start_DMA(&htim2, TIM_CHANNEL_1, buffer_comp, 4001);
	set_LED4(1);
	state.compMeasuring = 1;
	//keep "preparedToRunMeasurementPhase" low -> when mode is 1, in interrupt it can be set to high...
	state.preparedToRunMeasurementPhase = 0;
}

void measurementWithExtAdcDone() {

	//stop DMA
	SPI1->CR2 &= ~SPI_CR2_RXDMAEN;

	filledBuffersExtADC++;
	//first buffer is filled
	if (filledBuffersExtADC == 1) {
		//start DMA again with second buffer
		HAL_SPI_Receive_DMA(&hspi1, buffer_extAdc_2.uint8, samplesPerPeriod);
	}

	//second buffer is filled, send data over UART
	else if (filledBuffersExtADC == 2) {
		// turn off timers
		HAL_TIM_PWM_Stop_IT(&htim1, TIM_CHANNEL_1);
		HAL_TIM_PWM_Stop_IT(&htim1, TIM_CHANNEL_2);
		HAL_TIM_PWM_Stop_IT(&htim8, TIM_CHANNEL_1);

		// stop measuring
		set_LED2(0);
		state.extAdcReadyToSend = 1;
		state.extAdcMeasuring = 0;

		filledBuffersExtADC = 0;

		goToIdleAfterMeasurement();
		//if this is the last measurement, go to idle state
		if (state.remainingMeasurements == 0) {
			state.extAdcActiveState = 0;
			state.extAdcSetState = 0;
		} else {
			prepareForPolarizationPhaseIfPossible();
		}
	}
}

void measurementWithIntAdcDone() {
	//stop the ADC when in interrupt
	//if function HAL_ADC_Stop_DMA(&hadc1) would be called, it wouldn't be possible to Start DMA again.
	ADC1->CR2 &= ~ADC_CR2_DMA;

	filledBuffersIntADC++;

	//first buffer is filled
	if (filledBuffersIntADC == 1) {
		HAL_ADC_Start_DMA(&hadc1, (uint32_t*) &buffer_intAdc_2.uint16, samplesPerPeriod);
	}

	//second buffer is filled, stop measuring
	else if (filledBuffersIntADC == 2) {
		// turn off timer
		HAL_TIM_Base_Stop_IT(&htim6);

		set_LED3(0);
		filledBuffersIntADC = 0;
		state.intAdcReadyToSend = 1;
		state.intAdcMeasuring = 0;

		goToIdleAfterMeasurement();

		//if this is the last measurement, go to idle state
		if (state.remainingMeasurements == 0) {
			state.intAdcActiveState = 0;
			state.intAdcSetState = 0;
		}
		// if there are remaning
		else {
			prepareForPolarizationPhaseIfPossible();
		}
	}
}

void measurementWithCompDone(TIM_HandleTypeDef *htim) {
	HAL_TIM_IC_Stop_DMA(&htim2, TIM_CHANNEL_1);
	set_LED4(0);
	state.compReadyToSend = 1;
	state.compMeasuring = 0;

	goToIdleAfterMeasurement();

	//if freq should be measured only once, after the measurement, go to idle state
	if (state.remainingMeasurements == 0) {
		state.compActiveState = 0;
		state.compSetState = 0;
	} else {
		prepareForPolarizationPhaseIfPossible();
	}
}

//comparator finished measuring
void HAL_TIM_IC_CaptureCallback(TIM_HandleTypeDef *htim) {
	if (htim->Instance == TIM2) {
		measurementWithCompDone(htim);
	}
}

//intADC - buffer filled
void HAL_ADC_ConvCpltCallback(ADC_HandleTypeDef *hadc) {
	if (hadc->Instance == ADC1) {
		measurementWithIntAdcDone();
	}
}

//char received with via USB
void HAL_UART_RxCpltCallback(UART_HandleTypeDef *huart) {
	if (huart->Instance == USART3) {
		//receivedCharIndex shouldn't exceed 100
		receivedChars[(receivedCharIndex++) % 100] = buffer_uart_rx[0];
		state.newDataInBuffer = 1;
		HAL_UART_Receive_IT(&huart3, buffer_uart_rx, 1);
	}
}


//extADC - buffer filled
void HAL_SPI_RxCpltCallback(SPI_HandleTypeDef *hspi) {
	if (hspi->Instance == SPI1) {
		measurementWithExtAdcDone();
	}
}

/* USER CODE END 4 */
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


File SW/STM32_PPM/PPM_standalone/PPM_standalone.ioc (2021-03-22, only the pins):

Mcu.UserName=STM32F767VITx
PA0/WKUP.GPIO_Label=Amp_fil_sig-int_ADC
PA0/WKUP.Signal=ADCx_IN0
PA13.Signal=SYS_JTMS-SWDIO
PA14.Signal=SYS_JTCK-SWCLK
PA15.GPIO_Label=Comp
PA15.Signal=S_TIM2_CH1_ETR
PA2.GPIO_Label=UART2-TX_RS232
PA2.Signal=USART2_TX
PA3.GPIO_Label=UART2-RX_RS232
PA3.Signal=USART2_RX
PA4.GPIO_Label=SPI1-NSS_for_MCU
PA4.Signal=SPI1_NSS
PA5.GPIO_Label=SPI1-CLK_ext_ADC
PA5.Signal=SPI1_SCK
PA6.GPIO_Label=LT1777-SYNC
PA6.Signal=S_TIM3_CH1
PA7.GPIO_Label=SPI1-MOSI_ext_ADC
PA7.Signal=SPI1_MOSI
PA8.Signal=I2C3_SCL
PB10.GPIO_Label=UART3-TX_FT230
PB10.Signal=USART3_TX
PB11.GPIO_Label=UART3-RX_FT230
PB11.Signal=USART3_RX
PB12.GPIO_Label=SYNC
PB12.Signal=GPXTI12
PB14.GPIO_Label=UART1-TX
PB14.Signal=USART1_TX
PB15.GPIO_Label=UART1-RX
PB15.Signal=USART1_RX
PB3.Signal=SYS_JTDO-SWO
PB6.Signal=I2C1_SCL
PB7.Signal=I2C1_SDA
PC14/OSC32_IN.Signal=RCC_OSC32_IN
PC15/OSC32_OUT.Signal=RCC_OSC32_OUT
PC3.GPIO_Label=SN6505-EN
PC3.Signal=GPIO_Output
PC6.GPIO_Label=Gen_SPI1-CLK_for_ext_ADC
PC6.Signal=S_TIM8_CH1
PC7.GPIO_Label=BTN1
PC7.Signal=GPXTI7
PC8.GPIO_Label=BTN2
PC8.Signal=GPXTI8
PC9.Signal=I2C3_SDA
PD0.GPIO_Label=Switches_driver_enable
PD0.Signal=GPIO_Output
PD1.GPIO_Label=S1
PD1.Signal=GPIO_Output
PD10.GPIO_Label=LED1-B
PD10.Signal=GPIO_Output
PD11.GPIO_Label=SN6505-EN
PD11.Signal=GPIO_Output
PD12.GPIO_Label=SN6505-SYNC
PD12.Signal=S_TIM4_CH1
PD13.GPIO_Label=LED2
PD13.Signal=GPIO_Output
PD14.GPIO_Label=LED3
PD14.Signal=GPIO_Output
PD15.GPIO_Label=LED4
PD15.Signal=GPIO_Output
PD2.GPIO_Label=S2
PD2.Signal=GPIO_Output
PD3.GPIO_Label=S3
PD3.Signal=GPIO_Output
PD4.GPIO_Label=S4
PD4.Signal=GPIO_Output
PD5.GPIO_Label=S5
PD5.Signal=GPIO_Output
PD6.GPIO_Label=S6
PD6.Signal=GPIO_Output
PD8.GPIO_Label=LED1-R
PD8.Signal=GPIO_Output
PD9.GPIO_Label=LED1-G
PD9.Signal=GPIO_Output
PE11.GPIO_Label=Gen_SPI1-NSS_ext_ADC
PE11.Signal=S_TIM1_CH2
PE2.Signal=SPI4_SCK
PE4.Signal=SPI4_NSS
PE5.Signal=SPI4_MISO
PE6.Signal=SPI4_MOSI
PE7.Signal=UART7_RX
PE8.Signal=UART7_TX
PE9.GPIO_Label=Gen_SP1I-NSS_MCU
PE9.Signal=S_TIM1_CH1
PH0/OSC_IN.Signal=RCC_OSC_IN
PH1/OSC_OUT.Signal=RCC_OSC_OUT

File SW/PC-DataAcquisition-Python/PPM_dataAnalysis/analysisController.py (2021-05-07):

import numpy as np 
import matplotlib.pyplot as plt 
import csv
import math
from scipy.signal import hilbert, chirp
from scipy.fft import fft, fftfreq

import frequencyAnalysis as fa
import fileManagement as fm
import communicationManagement as cm


def analyseDatafthroughUSB (port, baudrate, messageCountPerMeasurement, countOfMeasurements, fileName):
    # create label in result.csv file
    fm.appendColumnsToCSV(path='generatedFiles/results.csv',time="time", column1="hilbert transform", column2="fft without zero padding", column3= "fft with zero padding (bin width of 10 mHz)",column4= "fft with zero padding (bin width of 100 mHz)", column5 = "comparator")
    measurementIndex = 0    # current index of measurement
    inf = 0                 # if enabled, the measurement goes infiniti times
    
    # set infinity to 1 and make countOfMeasurements positive number
    if(countOfMeasurements  == -1):
        inf = 1
        countOfMeasurements = 1
    while measurementIndex < countOfMeasurements:
        # open file with measured data
        receivedRows = cm.receiveMessage(port = port, baudrate = baudrate, desiredCountOfReceivedMessages = messageCountPerMeasurement)

        #store data into file
        with open(fileName, mode='a') as csvFile:
            csvFileWriter = csv.writer(csvFile, delimiter=',', quotechar='"', lineterminator='\n', quoting=csv.QUOTE_MINIMAL)
            index = 0
            while index < len(receivedRows):   
                try:
                    csvFileWriter.writerow([receivedRows[index]])
                except:
                    print(receivedRows[index])
                index+=1
        
        fh = receivedRows
        analyseData(fh)
        if(inf == 0):
            measurementIndex +=1

def analyseDataFromFile(nameOfFile):
    fh = open(nameOfFile) #test.txt
    # create label in result.csv file
    fm.appendColumnsToCSV(path='generatedFiles/results.csv',time="time", column1="hilbert transform", column2="fft without zero padding", column3= "fft with zero padding (bin width of 10 mHz)",column4= "fft with zero padding (bin width of 100 mHz)", column5 = "comparator")
    analyseData(fh)
    fh.close

def analyseData(fh):
    
    # indexes that help analyse only the interesting part of signal    
    comparator_startIndex = 25
    comparator_endIndex = 400
    adc_startIndex = 500
    adc_stopIndex = 8820

    #sample frequency
    fs = 216000000/4898

    
    enableCSV = 0                   #if enabled, all measurements are stored in separate csv file
    enablePlot_measuredSignal = 1   #if enabled, the measured signal with ADC is stored as a picture
    enablePlot_comparator = 1       #if enabled, the measured signal with comparator is stored as a picture


    # x and y axis values 
    x = [] 
    y = [] 


    #hilbert transform 
    f_hilbertTransform = 0
    B_hilbertTransform = 0
    
    #FFT without zero paddding 
    f_fft_noZeroPadding = 0
    B_fft_noZeroPadding = 0

    #FFT with zero paddding (bin width - 10 mHz)
    f_fft_zeroPadding1 = 0
    B_fft_zeroPadding1 = 0

    #FFT with zero paddding (bin width - 100 mHz) 
    f_fft_zeroPadding2 = 0
    B_fft_zeroPadding2 = 0

    #comparator 
    f_comparator = 0
    B_comparator = 0
            

    procesingDataFromMeasurement = 0    # indication, if currently readed data are values for measurement
    graphTitle = ""                     # title of graph that consists of measurement index and method
    measurementMethod = ""              # current measurement method
    previousSample = 0                  # previous measurement index -> if changed, next measurement will be processed and 

    stepIndex = 0 
    lineIndex = 0

    try:
       
        for line in fh:
            #find nearest message with measured data
            foundHeadOfCommand = line.find("<")   #if there is "<" character in the line - head of command was found
            foundTailOfCommand = line.find(">")   #if there is ">" character in the line - tail ofcommand was found
            
            #Command line
            if foundHeadOfCommand >= 0:

                # null arrays
                stepIndex = 0
                x = [] 
                y = [] 
                #remove first and last character       
                commandText = line[1:-1]           
                commandArgs = commandText.split(":")

                if commandArgs[0] == 'INFO':
                    print(commandText)        
                elif commandArgs[0] == 'MEAS':
                    procesingDataFromMeasurement = 1
                    graphTitle = commandArgs[1] +""+ commandArgs[2]
            
            #found end of command    
            elif foundTailOfCommand >= 0:
                #if there is a new sample, save existing samples
                if(commandArgs[1] != previousSample):
                    print("Started execution of " + str(commandArgs[1]) +". sample")
                    if(previousSample != 0):
                        # write result into file
                        fm.appendColumnsToCSV(path='generatedFiles/results.csv',time= ((int(previousSample) - 1) * 8), column1= B_hilbertTransform, column2= B_fft_noZeroPadding, column3= B_fft_zeroPadding1,column4= B_fft_zeroPadding2, column5 = B_comparator)
                previousSample = commandArgs[1]

                if procesingDataFromMeasurement == 1 and (commandArgs[2] == "extADC" or  commandArgs[2] == "intADC"):
                    
                    if(enableCSV):
                        #write into csv
                        fm.saveOneColumnToCSV(path = 'generatedFiles/csv/' + graphTitle + '.csv', column = y)
                    
            
            
                
                    # determine analytic signal                    
                    f_hilbertTransform = fa.computeFrequencyWithHilbertTransform(signal = y, startSample = adc_startIndex, endSample = adc_stopIndex, fs = fs)
                    B_hilbertTransform = f_hilbertTransform/(42.577478518 * pow(10, -3)) 
                    print("    Calculations - ADC - hilbert transform")
                    print('        f = '+ str(f_hilbertTransform)+ ' Hz')
                    print('        B = '+ str(B_hilbertTransform)+ ' nT')

                    
                    
                    f_fft_noZeroPadding = fa.computeFFTOfSignal(startSample = adc_startIndex, endSample = adc_stopIndex, signal = y, fs = fs)
                    B_fft_noZeroPadding  = f_fft_noZeroPadding/(42.577478518 * pow(10, -3)) 
                    print("    Calculations - ADC - with fft zero padding")
                    print('        f = '+ str(f_fft_noZeroPadding)+ ' Hz')
                    print('        B = '+ str(B_fft_noZeroPadding)+ ' nT')
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

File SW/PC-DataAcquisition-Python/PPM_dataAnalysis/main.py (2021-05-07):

import analysisController
import communicationManagement


def main():
    #message = b'<MEAS:extADC:INF>'
    #analysisController.analyseDatafthroughUSB(port = "COM9", baudrate = 2000000, messageCountPerMeasurement = 2, countOfMeasurements = -1, fileName = 'out2.txt' )
    analysisController.analyseDataFromFile(nameOfFile = 'meas1.txt' )

if __name__ == "__main__":
    main()

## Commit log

2020-11-05 Working communication with MAX11100 over SPI
    SPI:
    receive only mode
    sending via interrupt generated with timer14
2020-11-05 SPI controlled via DMA from timer interrupt
    Configured in order to control the SPI via DMA... problem with clk -> 40 edges instead of 24 edges
    [PPM_nucleo.ioc, main.c]
2020-11-05 receiving ADC data from MAX11100 with frequency 44100 Hz and sending ADC value on UART
    It works, but it needs to be improved
    - data are sending on UART from callback
    - data are not stored to MCU over DMA
2020-11-15 Receive SPI signal (as slave) from external ADC over DMA
    In order to achieve saving only 2 bytes instead of 3 bytes (1. byte is always null) from external ADC, 2 timers were used
    TIM1 - Generates NSS for external ADC and NSS for MCU. NSS for MCU us low on 8th pulse of clk.
    TIM8 - generates 24 clk pulses and is triggerd on update event from TIM1.
2020-11-16 Modified SPI receive callback
    In order to be able to measure more than 65535 packets over DMA the code was modified. In the SPI receive callback was added part, where the function "HAL_SPI_Receive_DMA" is called again, but with empty buffer, so it is possible to store 2* 65535 pakcets.
    Only problem is that the DMA is set all ower again, when all the data are received.
    Also, DMA low layer API was generated
    [PPM_nucleo.ioc, main.c, main.h]
2020-11-19 Added Input Capture timer to determine frequency from comparator
    In order to determine frequency from external comparator, TIM2 (32-bit) in input caputre mode was used.
2020-11-23 Modified UART communication
    Data are now measured for time 2 seconds. After that 2 buffers are transfered via UART into computer
    - Modified order of bytes in existing uart communication. It was necessary beacuse befor in the code the data was obtained from SPI. Now the data are saved via DMA and the bytes order is "switched"
    ToDo: Frequency computation needs to be optimized
2020-12-06 Modified SPI pins
    Pins that will be used in PPM stand alone version were used in order to check, if everithing works with them.
2021-01-11 increased speed of UART from 115 200 bps to 2 000 000 bps
2021-01-13 added sechematic
    [PPM.sch]
2021-01-13 added PCB
    [PPM.kicad_pcb]
2021-01-13 added gerber files
    [PPM-B_Cu.gbr, PPM-B_Mask.gbr, PPM-Edge_Cuts.gbr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]
2021-01-13 added bill of materials
    [BOM2.xlsx]
2021-01-13 Revert "Merge of PPM_standalone and PPM_nucleo versions"
    This reverts commit 0c80d330299ece87dfb9f1d4d4a5a3ec8442ced6.
    [main.c, main.h]
2021-01-13 Added data acquisition scripts
    csvDataAnalysis.py - testing script that stores data into csv file
    serialCommunicationExample.py - testing script that enables communication over Serial port
    STM32_Communication.py - script that enables data acquisition from STM32
    [test.csv]
2021-01-13 Revert "added new file with PPM_Nucleo code"
    This reverts commit b46cfa1d329759f94158fa1d5495cf02862698f2.
    [PPM_nucleo.ioc, main.c, main.h]
2021-01-14 changed Bill Of Material to correspond with filled cart on mouser
    [BOM2.xlsx]
2021-01-14 added script "createPlot-example.py" that creates plot and implemented feature in the main script
    [test.csv]
2021-01-15 changed Bill Of Material to correspond with filled cart on mouser
    Added resistors around filter
    [BOM2.xlsx]
2021-01-18 added the rest of components
    [BOM2.xlsx]
2021-01-21 Added possibility to send data from PC to board
2021-01-31 added code that enables internal ADC controled by DMAand triggered by timer
2021-02-03 fixed errors after merge
    [PPM_nucleo.ioc, main.c, main.h]
2021-02-03 control of switching circuit was merged
    It runs before measuring phase
2021-02-03 Tasks merged, but continuous mode has some bugs
    [main.c]
2021-02-03 changed print functions to make it easier for analysis
2021-02-08 implemented LED blinking on PPM standalone version
2021-02-08 implemented switching circuit control management
    Still needs to be tested on board
2021-02-11 bugfix - SPI communication set to 16bit on standalone version
    [PPM_standalone.ioc, main.c]
2021-02-11 bugfix - changed timer to timer 6 on standalone version
    [PPM_standalone.ioc, main.c]
2021-02-22 fixed problem with ADC over DMA
    In order to stop DMA conversion, it's necessary to set only register ADC1->CR2 &= ~ADC_CR2_DMA. if function HAL_ADC_Stop_DMA(&hadc1) would be called, it wouldn't be possible to Start DMA again.
    [Amp1.csv, Amp2.csv, Amp3.csv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]
2021-02-23 modified measuring of frequency via comparator
    - now the timer stores values over DMA into buffer
    - bugfix of timer robustness
    [PPM_standalone.ioc, main.c]
2021-02-26 UART communication improvement
    In order to make the UART communication more stable and to have more options, UART communication was changed.
2021-02-27 bugfix - measurment method can be changed without any problems
    [main.c]
2021-02-27 fixed problem with count of measurements
    [main.c]
2021-03-01 fixed bugs and improved robustness+ add feature to change polarization time
    [PPM_standalone.ioc, main.c]
2021-03-01 Added comments to make the code more clear, added possibility to stop measuring through UART
2021-03-02 improved stability with change of priorities, increased robustness of code and implemented desktop application
    [test.csv]
2021-03-03 Added feature on STM32 - measure every 20 seconds to keep constant period.
    the 20 seconds wait period runs in timer 5 (the same as timer used for delays)
    [1extADC.csv, 1intADC.csv, test.csv]
2021-03-03 fixed bugs in schema
    [PPM.sch]
2021-03-04 changed TIM5 period to 50 us
    [PPM.sch]
2021-03-08 Modified getDataFromText.py script in order to see more details of signal
    [10comp.csv, 10extADC.csv, 10intADC.csv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]
2021-03-12 Small modifications in python data acquisition script and polarization sequence in PPM_standalone was improved
    added state in polarization sequence
    [10comp.csv, 10extADC.csv, 10intADC.csv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]
2021-03-14 added script to plot measured data from oscilloscope and fixed bug with SPI
    bugfix:
    boosted priority of DMA2 for SPI communication in order to fix problems with busy wait after RX. It seems that when he priority was low, than sometimes the settings for DMA wasn't fast enough and than it missed some data
    [PPM.sch]
2021-03-15 added possibility to start MCU with measuring instead of polarization
    [1intADC.csv, 43extADC.csv, 46extADC.csv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]
2021-03-22 change of polarization sequence - it still needs work
    [10extADC.csv, 11extADC.csv, 12extADC.csv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]
2021-04-15 The device was constructed and finally bring to live
    There were some mistakes that are now fixed in schema, but still wrong on PCB. Keep it in mind...
    [BOM2.xlsx, PPM.sch, Switching circuit.kicad_pcb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]
2021-04-20 improved data analysis in python in order to determine frequency using hilbert transform
    Also small modifications in firmware were implemented
    - fixed time between measurements
    - default measurement method is comparator with extADC
    [100comp.csv, 100extADC.csv, 101comp.csv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]
2021-05-04 firmware code was split from main to dedicated files to make the code more readable
    [10comp.csv, 10extADC.csv, 11comp.csv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]
2021-05-04 modification of python code hierarchy
    [Amp1.csv, Amp2.csv, Amp3.csv]
2021-05-04 created python script that enables communication with STM32 standalone board
    [results.csv]
2021-05-04 fixed bug related to uart parse text on STM32. Also finished script in python that analyze and save measured data
    [results.csv]
2021-05-07 fixed bug related to data analysis in python
    [results.csv]

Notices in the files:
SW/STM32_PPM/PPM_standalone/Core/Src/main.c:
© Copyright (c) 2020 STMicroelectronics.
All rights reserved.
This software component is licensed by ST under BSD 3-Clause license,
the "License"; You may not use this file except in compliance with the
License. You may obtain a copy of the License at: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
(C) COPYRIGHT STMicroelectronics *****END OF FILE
